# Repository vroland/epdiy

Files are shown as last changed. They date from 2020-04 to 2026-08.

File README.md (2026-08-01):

  

EPDiy E-Paper Driver
=======================================

EPDiy is a driver board which talks to affordable E-Paper (or E-Ink) screens, which are usually sold as replacement screens for E-Book readers. Why are they interesting?

* Easy on the eyes and paper-like aesthetics
* No power consumption when not updating
* Sunlight-readable

Ready-made DIY modules for this size and with 4bpp (16 Grayscale) color support are currently quite expensive and / or slow.
The EPDiy controller can drive the bare display modules, e.g. from old e-Readers, which are available for 20$ (small) / 30$ (large) on ebay!
Additionally, since it is based on the ESP32S3 (V7) / ESP32 (V2-V6) microcontroller, it features WiFi and Bluetooth connectivity.

The EPDiy driver board targets a range of E-Paper displays, as shown in the table below.
As the driving method for all matrix-based E-ink displays is more or less the same, only the right connector and timings are needed.
The current V7 board has three different display connectors, other display will require an adapter board.

The controller is optimized for the use with LiPo batteries, featuring a LiPo charger and ultra-low deep sleep current.

This project supports a driver for the ESP-IDF and Arduino. For installation instructions, please refer to the [documentation](https://epdiy.readthedocs.io/en/latest/getting_started.html#getting-your-board).
Note that for epdiy V7, update speeds are significantly lower when using the Arduino IDE, because it does not allow to change
the sub-optimal cache configuration.

Get Inspired
------------

The `examples` directory contains some example applications like a weather station or a screen diagnostic test. 
If you want to build something more useful though, how about:

- A serial terminal for connecting to a raspberry pi: [video](https://cdn.hackaday.io/files/1681937195969312/terminal_demo.mp4) [repository](https://github.com/vroland/epdiy-terminal)]
- A Music Player Daemon (MPD) dashboard: [repository](https://github.com/vroland/epdiy-mpd)]
- Firmware for displaying images directly from Immich (Self-Hosted Photo Management) [epdiy-immich](https://github.com/vroland/epdiy-immich)
- An e-Paper picture frame: [video](https://www.youtube.com/watch?v=r7AcNQsSZUw)
- And more to come!

Building It
-----------

On the [EPDiy Hardware Page](https://vroland.github.io/epdiy-hardware/), you'll find a list of all boards and variants, adapters, and helpers.
Next to each board, there are manufacturing files (gerbers), Bill of Materials (BoM), part placement files,
and 3D models ready to use!

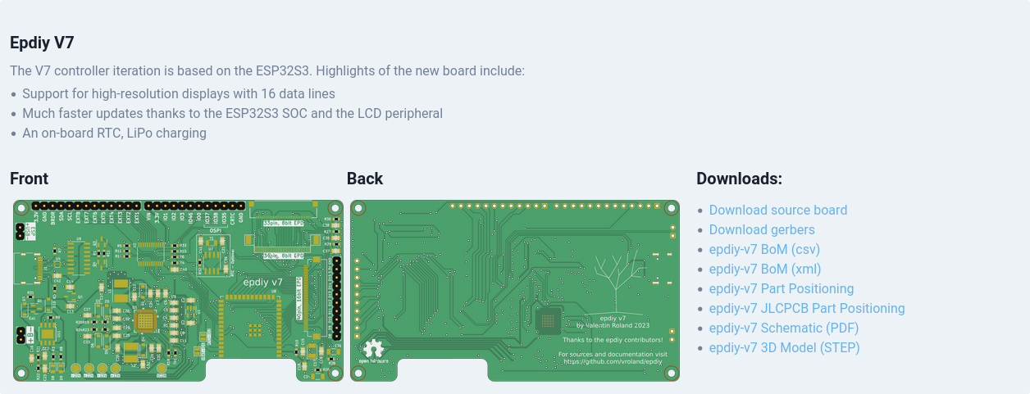
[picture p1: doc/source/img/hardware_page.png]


For ordering from JLCPCB for example, ordering is as easy as downloading the zipped gerbers, BoM, and placement file
and uploading them. The process is very similar for other manufacturers, check your vendor's documentation for details.
Don't forget to oder adapters if the board doesn't have connectors for your specific display.

The current latest version is epdiy V7, beased on the ESP32S3. 
Older versions are also available on the hardware page.

#### Contributing Hardware

Want to contribute your own board variant or adapter? 
Check out the [epdiy-hardware repository](https://github.com/vroland/epdiy-hardware) for instructions.

Gettings Started
----------------

For instructions and more information visit the [documentation](https://epdiy.readthedocs.io/en/latest/getting_started.html)!

Join the Discussion
----------------

 -  Matrix Community: +epdiy:matrix.vroland.de
 - Slack: See badge

Displays
--------

|Name |Size |Resolution|Compatible|Connector|Pin count|Compatible since pcb version|Notes
| --: | --: | --: | --: | --: | --: | --: | --: |
| ED060SC4 | 6"  | 800 x 600<br>167 PPI | yes, tested | FH26W-39S-0.3SHW(60) | 39  | v2  | |
|ED097OC4|9.7"|1200 x 825<br>150 PPI|yes, tested|XF2M-3315-1A|33|v2|Cheap, inferior contrast
|ED097TC2|9.7"|1200 x 825<br>150 PPI|yes, tested|XF2M-3315-1A|33|v2|Slightly higher price, better contrast
|ED097OC1|9.7"|1200 x 825<br>150 PPI|yes (should work)|XF2M-3315-1A|33|v2|Cheap, inferior performance
|ED047TC1|4.7"|960 x 540<br>234 PPI|yes, tested|40-pin|40|LILYGO 4.7" EPD|Supported only by 4.7" e-paper board by LILYGO
| ED050SC5 | 5" | 600 x 800<br>200 PPI | yes, tested | THD0510-33CL-GF | 33 | v5 |
| ED050SC3 | 5" | 600 x 800<br>200 PPI | yes (should work) | THD0510-33CL-GF | 33 | v5 |
| ED052TC4 | 5.2" | 1280 x 720<br>284 PPI | yes (should work) | WP27D-P050VA3 | 50 | v5 |
| ED133UT2 | 13.3" | 1600 x 1200<br>150 PPI | yes, tested | adapter board | 39 | v2 | Adapter Board required, also PENG133D
| ED060XC3 | 6" | 758 x 1024<br>212 PPI | yes, tested | THD0515-34CL-SN | 34 | v5 | Cheapest, good contrast and resolution
| ED060XD4 | 6"  | 758 x 1024<br>212 PPI | yes, tested | THD0515-34CL-SN | 34 | v5 |
| ED060XC5 | 6"  | 758 x 1024<br>212 PPI | yes (should work as ED060XC3) | THD0515-34CL-SN | 34 | v5 |
| ED060XD6 | 6"  | 758 x 1024<br>212 PPI | yes (should work as ED060XC3) | THD0515-34CL-SN | 34 | v5 |
| ED060XH2 | 6"  | 758 x 1024<br>212 PPI | yes (should work as ED060XC3) | THD0515-34CL-SN | 34 | v5 |
| ED060XC9 | 6"  | 758 x 1024<br>212 PPI | yes (should work as ED060XC3) | THD0515-34CL-SN | 34 | v5 |
| ED060KD1 | 6"  | 1072 x 1448<br>300 PPI | yes (should work as ED060XC3) | THD0515-34CL-SN | 34 | v5 |
| ED060KC1 | 6"  | 1072 x 1448<br>300 PPI | yes (should work as ED060XC3) | THD0515-34CL-SN | 34 | v5 |
| ED060SCF | 6" | 600 x 800<br>167 PPI | yes, tested | THD0515-34CL-SN | 34 | v5 | Different flex cable shape
| ED060SCN | 6" | 600 x 800<br>167 PPI | yes (should work as ED060XC3) | THD0515-34CL-SN | 34 | v5 | Different flex cable shape
| ED060SCP | 6" | 600 x 800<br>167 PPI | yes (should work as ED060XC3) | THD0515-34CL-SN | 34 | v5 | Different flex cable shape
| ED060SC7 | 6" | 600 x 800<br>167 PPI | yes (should work) | AXT334124 | 34 | v5 | connector dropped in v6
| ED060SCG | 6"  | 600 x 800<br>167 PPI | yes (should work) | AXT334124 | 34 | v5 | connector dropped in v6
| ED060SCE | 6"  | 600 x 800<br>167 PPI | yes (should work) | AXT334124 | 34 | v5 | connector dropped in v6
| ED060SCM | 6"  | 600 x 800<br>167 PPI | yes (should work) | AXT334124 | 34 | v5 | connector dropped in v6
| ED060SCT | 6"  | 600 x 800<br>167 PPI | yes, tested | AXT334124 | 34 | v5 | connector dropped in v6
| ED078KC1 | 7.8"  | 1872 x 1404<br>300 PPI | yes, tested | FH12-40S-0.5SH | 40 | v7 | 16 data lines

Troubleshooting
---------------

The following list is compiled from past experiences and GitHub issues:
 * **The displayed image displays only part of the image.** Make sure to select the correct display type as described [here](https://epdiy.readthedocs.io/en/latest/getting_started.html#selecting-a-display-type).
 * **The existing image fades / darkens when updating a partial screen region.** Make sure the VCOM voltage is [calibrated](https://epdiy.readthedocs.io/en/latest/getting_started.html#calibrate-vcom) for your specific display.
 * **The second third of the image is replaced with the last third.** This seems to be a timing issue we could not yet quite figure out the reason for. For a workarround or suggestions please [join the discussion](https://github.com/vroland/epdiy/issues/15).
 * **The ESP does not boot correctly when external periperals are connected.** Make sure not to pull GPIO12 high during boot, as it is a strapping pin internal voltage selection (https://github.com/vroland/epdiy/issues/17).
 * **The ESP power consumption in deep sleep is too high.** Add `rtc_gpio_isolate(GPIO_NUM_12);` to your solution. See also [Configuring IOs (Deep-sleep Only)](https://docs.espressif.com/projects/esp-idf/en/latest/esp32/api-reference/system/sleep_modes.html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).

LilyGo Boards
---------------

### Supported LilyGo Boards

| Board | Display | Board Definition | Notes |
| --: | --: | --: | --: |
| LilyGo T5 4.7" | ED047TC1 | `epd_board_lilygo_t5_47` | Original T5 4.7" |
| LilyGo T5 S3 E-Paper Pro | ED047TC1 | `epd_board_v7` | ESP32-S3 based, includes GT911 touch, PCF8563 RTC, BQ25896/BQ27220 battery management |

### Power Management

There are several differences with these boards.
One particular one is the way the LilyGo handles power to the display the official lilygo code has two states.
This is now handled in epdiy in a different way to the lilygo code.
**epd_poweroff()** completely turns the power off to the display and the other peripherals of the lilygo.
The new function **epd_powerdown()** keeps the peripherals on (this allows the touch functions to continue to work).
**epd_poweroff() should always be called before sleeping the system**
You can still use touch to wake the screen with the following.
In Arduino it works like this.
`epd_poweroff();`

 `epd_deinit();`

 `esp_sleep_enable_ext1_wakeup(GPIO_SEL_13, ESP_EXT1_WAKEUP_ANY_HIGH);`

 `esp_deep_sleep_start();`

### I2C Bus Sharing

EPDIY now uses the ESP-IDF master bus/device I2C driver on IDF 5.x and newer.

Existing programs can keep calling `epd_init(...)` and EPDIY will create and own the board's default I2C bus.

If your application already owns an ESP-IDF I2C master bus, pass it in during initialization:

```c
i2c_master_bus_handle_t bus = ...;
EpdI2cConfig i2c_config = {
    .bus_handle = bus,
};
EpdInitConfig init_config = {
    .i2c = &i2c_config,
};

epd_init_with_config(&epd_board_v7, &ED047TC1, EPD_LUT_64K, &init_config);
```

When a bus handle is provided, EPDIY will attach its TPS65185/PCA9555 devices to that bus and leave bus ownership to the caller.

More on E-Paper Displays
------------------------

 * List of E-Paper devices and their screens: https://e-ink-reader.ru/chg_dsp_en.php (thanks, @mcer12)
 * Reverse engineering of display pins, possible starting point for alternative drivers: https://linux-sunxi.org/PocketBook_Touch_Lux_3 (thanks, @mcer12)
 * Reverse engineering and explanation on driving EPDs: http://essentialscrap.com/eink/index.html
 * Earlier take on driving 6" EPDs with an ESP32, basis of original power circuit: http://spritesmods.com/?art=einkdisplay&page=1
 * Related Hackaday projects: https://hackaday.io/project/21607 https://hackaday.io/project/11537

If you know any other useful resources or have suggestions, please comment on #31!

Hackaday Project
----------------

For more details, see the project page on Hackaday: https://hackaday.io/project/168193-epdiy-976-e-paper-controller

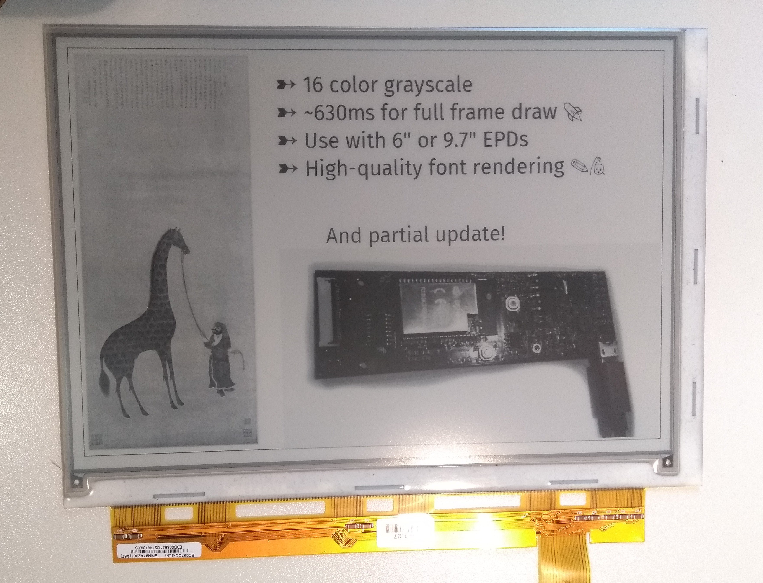
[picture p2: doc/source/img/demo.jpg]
demo image

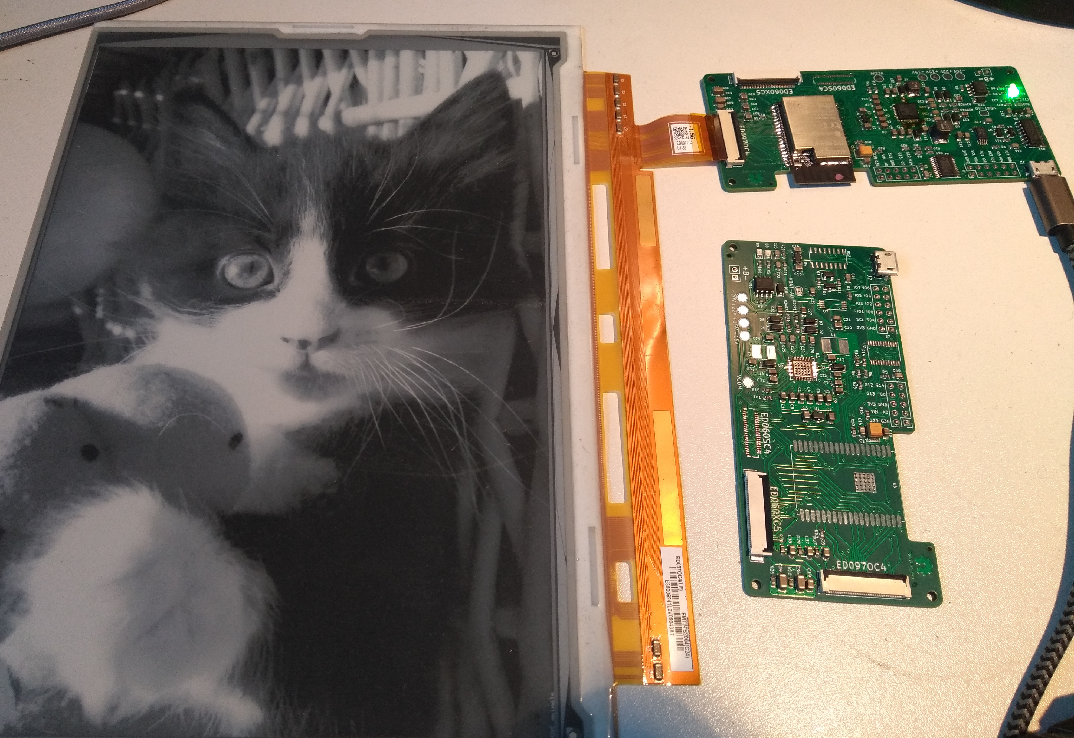
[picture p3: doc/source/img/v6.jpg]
board front


Licenses
--------

The weather example is Copyright (c) David Bird 2018 (except for minor modifications). Please refer to `examples/weather/README.md` for details.

The board and schematic are licensed under a  <a rel="license" href="https://creativecommons.org/licenses/by-sa/4.0/">Creative Commons Attribution-ShareAlike 4.0 International License</a>.

Firmware and remaining examples are licensed under the terms of the GNU Lesser GPL version 3.
Utilities are licensed under the terms of the MIT license.

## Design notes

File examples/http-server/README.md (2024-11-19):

# HTTP server

Runs an HTTP server that will draw images on the screen.  
Useful for setting up a small digital frame that can be remotely controlled.  

## Config
1. In `main/server.h`, edit `WIFI_SSID` and `WIFI_PASSWORD` to match your wifi config
2. In `main/main.c`, edit `n_epd_setup` to refer to the right EPD screen

## Running
flash (`idf.py flash`), then connect the EPDiy to a power source (computer is fine).  
The endpoints are:
1. `GET /`, prints the screen temp / height / width as headers
2. `POST /clear`, clears the screen
3. `POST /draw`, expects:
   1. a body that is a binary stream already encoded to EPDiy's standards (like the one in `dragon.h`).
   2. Headers `width`, `height`
   3. Optional headers `x`,`y` (default to 0)
   4. Optional header `clear`, if set to nonzero integer will force-clear the screen before drawing

## Helper script
`send_image.py` is a friendlier client.
```bash
$ ./send_image.py ESP_IP info
EpdInfo(width=1024, height=768, temperature=20)

$ ./send_image.py ESP_IP clear
# Clears the screen

$ ./send_image.y ESP_IP draw /tmp/spooder-man.png
# Draws on screen
```
Thanks to argparse, all arguments are visible with `--help`.  
Requires `requests` and `PIL` (or Pillow)

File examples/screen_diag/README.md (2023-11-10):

# Screen Diagnostics
This example app implements a simple shell to allow you to tinker with the display. You have access to all drawing functions from the _epd driver_, as well as system information, etc.

There are also pre-programmed algorithms (e.g. `render_stairs`, `render_grid`) which can be used to find pixel errors or display incompatibilities.

The `screen_diag` examples requires ESP-IDF v5.x or newer.

## Setup
Don't forget to set your display type in `epd_init` in `epd.c`!

First you need to flash the firmware:
```sh
idf.py flash
```

After that, you can enter the shell environment with:
```sh
idf.py monitor
```

Please note the [known issues](https://docs.espressif.com/projects/esp-idf/en/stable/esp32/api-guides/tools/idf-monitor.html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) of the IDF Monitor for limitations.

## Usage
You can get a full list (see below) of all available commands with: `help`.

```
system_restart
  Restarts the system.

free_heap_size
  Returns the free heap size.

dump_heaps_info  [<caps>]
  Dumps heap information of all heaps matching the capability.
        <caps>  Heap caps to print. Default: MALLOC_CAP_DEFAULT

dump_tasks
  Dumps all tasks with their names, current state and stack usage.

chip_info
  Dumps chip information.

firmware_info
  Dumps information about the ESP-IDF and the firmware.

get_time
  Returns the time in microseconds since boot.

get_mac  [<interface>]
  Returns the MAC address for the given interface or the pre-programmed base
  address.
   <interface>  Either "wifi_station", "wifi_ap", "bluetooth" or "ethernet"

get_rotation
  Get current screen rotation.

set_rotation  <rotation> [--inverted]
  Changes screen rotation.
    <rotation>  screen rotation: "horizontal" or "portrait"
    --inverted

get_width
  Print screen width.

get_height
  Print screen height.

get_pixel  <posx> <posy>
  Get pixel color in front buffer.
        <posx>  x position
        <posy>  y position

set_pixel  <posx> <posy> [<color>]
  Set pixel color in front buffer.
        <posx>  x position
        <posy>  y position
       <color>  color. default value: 0 (0x00)

clear_screen
  Clear the entire screen and reset the front buffer to white.

full_clear_screen
  Same as clear_screen, but also tries to get rid of any artifacts by cycling
  through colors on the screen.

get_temp
  Returns the ambient temperature.

power_on
  Turns on the power of the display.

power_off
  Turns off the power of the display.

draw_hline  <x> <y> <len> [<color>]
  Draw horizontal line.
           <x>  start x position
           <y>  start y position
         <len>  length of the line
       <color>  default value: 0x00

draw_vline  <x> <y> <len> [<color>]
  Draw vertical line.
           <x>  start x position
           <y>  start y position
         <len>  length of the line
       <color>  default value: 0x00

draw_line  <start_x> <start_y> <end_x> <end_y> [<color>]
  Draw line between two points.
     <start_x>  start x position
     <start_y>  start y position
       <end_x>  end x position
       <end_y>  end y position
       <color>  default value: 0x00

draw_rect  <x> <y> <width> <height> [<color>]
  Draw a rectangle.
           <x>  top left x position
           <y>  top left y position
       <width>  square width
      <height>  square height
       <color>  default value: 0x00

fill_rect  <x> <y> <width> <height> [<color>]
  Draw a filled rectangle.
           <x>  top left x position
           <y>  top left y position
       <width>  square width
      <height>  square height
       <color>  default value: 0x00

draw_circle  <center_x> <center_y> <radius> [<color>]
  Draw a circle.
    <center_x>  center x position
    <center_y>  center y position
      <radius>  circle radius
       <color>  default value: 0x00

fill_circle  <center_x> <center_y> <radius> [<color>]
  Draw a filled circle.
    <center_x>  center x position
    <center_y>  center y position
      <radius>  circle radius
       <color>  default value: 0x00

draw_triangle  <x0> <y0> <x1> <y1> <x0> <y0> [<color>]
  Draw a triangle from three different points.
          <x0>  first edge x position
          <y0>  first edge y position
          <x1>  second edge x position
          <y1>  second edge y position
          <x0>  third edge x position
          <y0>  third edge y position
       <color>  default value: 0x00

fill_triangle  <x0> <y0> <x1> <y1> <x0> <y0> [<color>]
  Draw a filled triangle from three different points.
          <x0>  first edge x position
          <y0>  first edge y position
          <x1>  second edge x position
          <y1>  second edge y position
          <x0>  third edge x position
          <y0>  third edge y position
       <color>  default value: 0x00

write_text  [-s] <x> <y> [<color>] <msg>
  Write text message to the screen using the sans-serif font by default.
           <x>  x position
           <y>  y position
       <color>  default value: 0x00
   -s, --serif  Use serif font rather than sans-serif.
         <msg>  Text to be printed.

render_stairs  [<slope>] [<width>] [<color>]
  Render multiple diagonal lines across the screen.
       <slope>  angle by which each diagonal line is drawn. default value: 3
       <width>  thickness of each diagonal line. default value: 100
       <color>  default value: 0x00

render_grid  [<gutter>] [<color>]
  Renders a grid across the whole screen. At a certain gutter size, cell info
  will be printed as well.
      <gutter>  default value: 75
       <color>  default value: 0x00

help
  Print the list of registered commands
```

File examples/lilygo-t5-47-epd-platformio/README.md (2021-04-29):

# LilyGo T5 4.7 Inch Example

This is an example project to kick-start you using the LilyGo T5 4.7 inch EPaper display.

It also incorporates a few deepsleep methods to show how to use deepsleep to effectively save battery.
Additionally, it inherits and modifies the battery calculation code provided in examples by the manufacturer.

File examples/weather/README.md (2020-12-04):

Weather display example
=======================================

This is **port of project https://github.com/G6EJD/ESP32-e-Paper-Weather-Display by David Bird 2018** to work with ED097OC4 Kindle display and this driver.
**Please note that David Bird (https://github.com/G6EJD) owns the copyright to this software!** Only minor modifications where made for it to run with the epdiy driver.
THe  license details are outlined in **License.txt**.

Building It
-----------

 - Girst you need to install Arduino esp-idf as a component https://github.com/espressif/arduino-esp32/blob/master/docs/esp-idf_component.md (the easiest way is to put it into components folder of ESP-IDF)
 - Put Arduino JSON https://github.com/bblanchon/ArduinoJson into components/arduino/
 - Dont forget to insert your Wi-Fi settings and openweathermap API key into owm_credentials.h
 - If you want to add more fonts, firmware may not fit into 1M and easiest way to fix it is to edit components/partition_table/partitions_singleapp.csv and change 1M to 2M

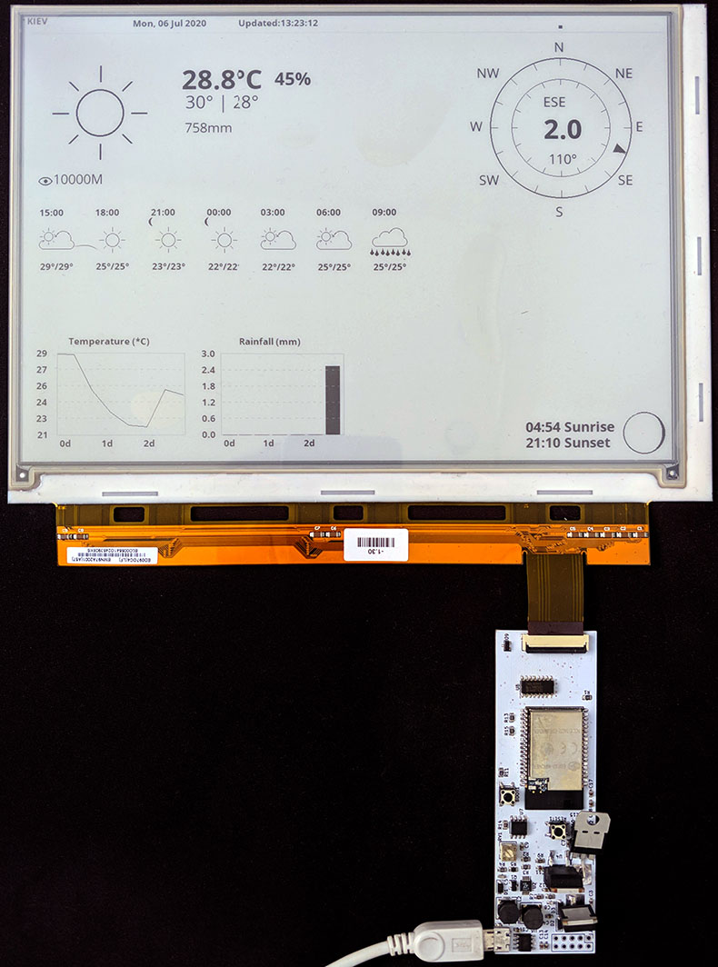
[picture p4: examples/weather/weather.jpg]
weather image


License
-------

This software, the ideas and concepts is Copyright (c) David Bird 2014 and beyond.

All rights to this software are reserved.
 
It is prohibited to redistribute or reproduce of any part or all of the software contents in any form other than the following:

 1. You may print or download to a local hard disk extracts for your personal and non-commercial use only.

 2. You may copy the content to individual third parties for their personal use, but only if you acknowledge the author David Bird as the source of the material.

 3. You may not, except with my express written permission, distribute or commercially exploit the content.

 4. You may not transmit it or store it in any other website or other form of electronic retrieval system for commercial purposes.

 5. You MUST include all of this copyright and permission notice ('as annotated') and this shall be included in all copies or substantial portions of the software and where the software use is visible to an end-user.
 
THE SOFTWARE IS PROVIDED "AS IS" FOR PRIVATE USE ONLY, IT IS NOT FOR COMMERCIAL USE IN WHOLE OR PART OR CONCEPT.

FOR PERSONAL USE IT IS SUPPLIED WITHOUT WARRANTY OF ANY KIND, EXPRESS OR IMPLIED, INCLUDING BUT NOT LIMITED TO THE WARRANTIES OF MERCHANTABILITY, FITNESS FOR A PARTICULAR PURPOSE AND NONINFRINGEMENT.

IN NO EVENT SHALL THE AUTHOR OR COPYRIGHT HOLDER BE LIABLE FOR ANY CLAIM, DAMAGES OR OTHER LIABILITY, WHETHER IN AN ACTION OF CONTRACT, TORT OR OTHERWISE, ARISING FROM, OUT OF OR IN CONNECTION WITH THE SOFTWARE OR THE USE OR OTHER DEALINGS IN THE SOFTWARE.

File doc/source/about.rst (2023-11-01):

About
=====

EPDiy is a driver board for e-Paper (or E-ink) displays.

.. _display_types:

Display Types
-------------

The EPDiy driver board targets multiple E-Paper displays.
As the driving method for all matrix-based E-ink displays seems to be more or less the same, only the right connector and timings are needed.
A table of supported displays is mainained in the :code:`README.md` file.

Some of the supported displays are showcased below.

ED097OC4
~~~~~~~~

The ED097OC4 was the original target of this project. It is an 9.7 inch screen, with a resolution of 1200 * 825 pixels (150dpi).
It is fairly available on Ebay and AliExpress, for around 30$ to 35$. 
There is also a lower contrast version (ED097OC1) which also works. 

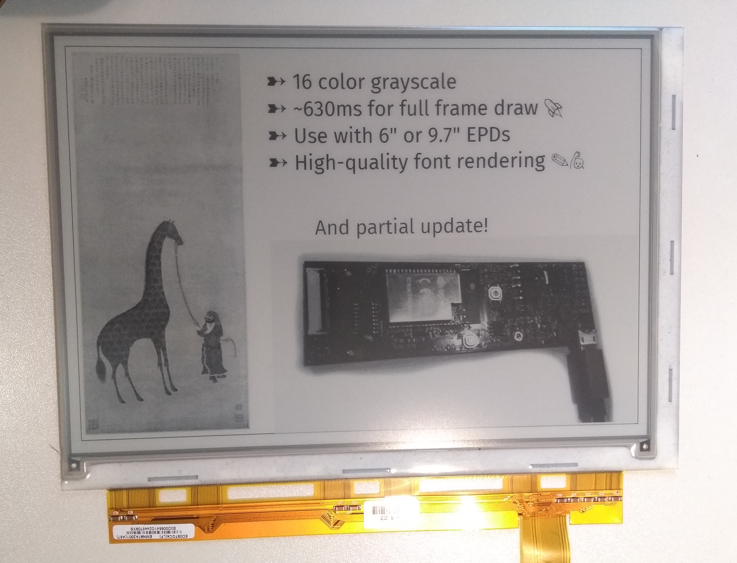
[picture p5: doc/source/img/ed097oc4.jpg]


ED060SC4
~~~~~~~~

This is a 6 inch display, with a 800 * 600 resolution. With 150dpi as well, it has about half the total display area of the ED097OC4.
To connect this display, the 39-pin connector on the back has to be populated.
It is also the display a lot of experimentation was done with (see Thanks To), so there are alternative controllers available.
Besides the obvious difference in size, this display is cheaper (~20$) and also refreshes slightly faster than the ED097OC4.

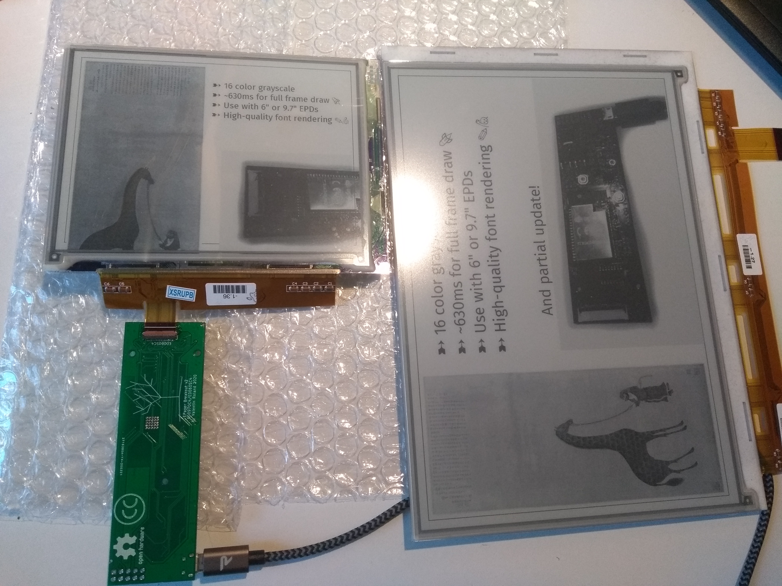
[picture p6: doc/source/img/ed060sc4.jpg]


ED097TC2
~~~~~~~~

Information on this display should be taken with a grain of salt. One of the displays I ordered as ED097OC4 came as ED097TC2,
and upon testing it also exhibited noticably better contrast and a more responsive electro-phoretic medium. 
The ribbon connector looked like a ED097TC2 as well, or like the `9.7 inch screens offered by Waveshare <https://www.waveshare.com/9.7inch-e-Paper.htm>` (which is sold for a lot more).
If you are on the lookout for such a display keep in mind the authenticity of my sample is disputable and resolution and connector type should be double-checked.

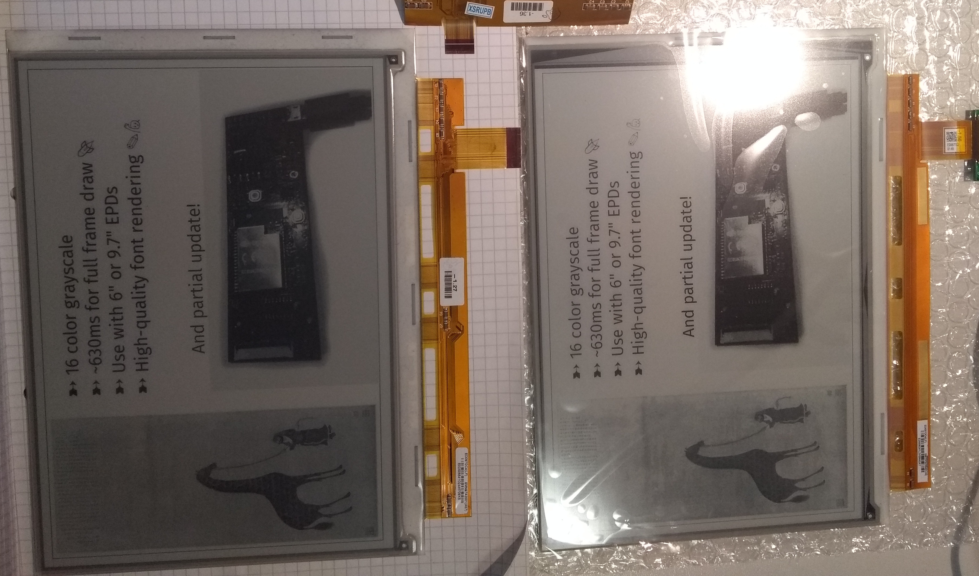
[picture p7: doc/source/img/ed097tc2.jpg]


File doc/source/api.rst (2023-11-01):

.. _pub_api:

Library API
===========

Highlevel API
-------------
.. doxygenfile:: epd_highlevel.h

Complete API
------------
.. doxygenfile:: epdiy.h

Internals
----------
.. doxygenfile:: epd_internals.h

Board-Specific Extensions
-------------------------
.. doxygenfile:: epd_board_specific.h

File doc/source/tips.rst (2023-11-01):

Tips & Tricks
=============

Temperature Dependence
----------------------

The display refresh speed depends on the environmental temperature.
Thus, if your room temperature is significantly different from ~22°C, grayscale
accuracy might be affected when using the builtin waveform.
This can be mitigated by using a different timing curve, but this would require calibrating the display timings at that temperature.
If you did this for some temperature other than room temperature, please submit a pull request!

Deep Sleep Current
------------------

Board Revision V5 is optimized for running from a battery thanks to its low deep sleep current consumption. 
In order to achieve the lowest possible deep sleep current, call
::

    epd_deinit()

before going to deep sleep. This will de-initialize the I2S peripheral used to drive the diplay and bring the pins used by epdiy to a low-power state.
You should be able to achieve a deep-sleep current of less than 13µA.
If your deep-sleep current is much higher, please check your attached peripherals.
With some modules, you have to isolate GPIO 12 before going to deep sleep:
::

    rtc_gpio_isolate(GPIO_NUM_12)

Adding a New Display
--------------------

This section is work-in-progress.

- Add display definitions in :code:`displays.c` and :code:`epd_display.h`.
- Include waveform in :code:`bulitin_waveforms.c`
- Calibrate timing curve in :code:`scripts/generate_epdiy_waveforms.py`.
- Add to the list of displays to build waveforms for in :code:`Makefile`
- Document

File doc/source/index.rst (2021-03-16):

.. EPDiy documentation master file, created by
   sphinx-quickstart on Sat Apr 18 23:41:08 2020.
   You can adapt this file completely to your liking, but it should at least
   contain the root `toctree` directive.

The EPDiy Driver Board
======================

.. toctree::
   :maxdepth: 2
   :caption: Quickstart:

   about.rst
   getting_started.rst
   filegen.rst
   tips.rst
   api.rst

EPDiy is a driver board which talks to affordable E-Paper (or E-Ink) screens, which are usually sold as replacement screens for E-Book readers. Why are they interesting?

* Easy on the eyes and paper-like aesthetics
* No power consumption when not updating
* Sunlight-readable

Ready-made DIY modules for this size and with 4bpp (16 Grayscale) color support are currently quite expensive. This project uses Kindle replacement screens, which are available for 20$ (small) / 30$ (large) on ebay!

The EPDiy driver board targets multiple E-Paper displays. As the driving method for all matrix-based E-ink displays seems to be more or less the same, only the right connector and timings are needed. The EPDiy PCB features a 33pin and a 39pin connector, which allow to drive the following display types: ED097OC4, ED060SC4, ED097TC2

:ref:`getting_started`



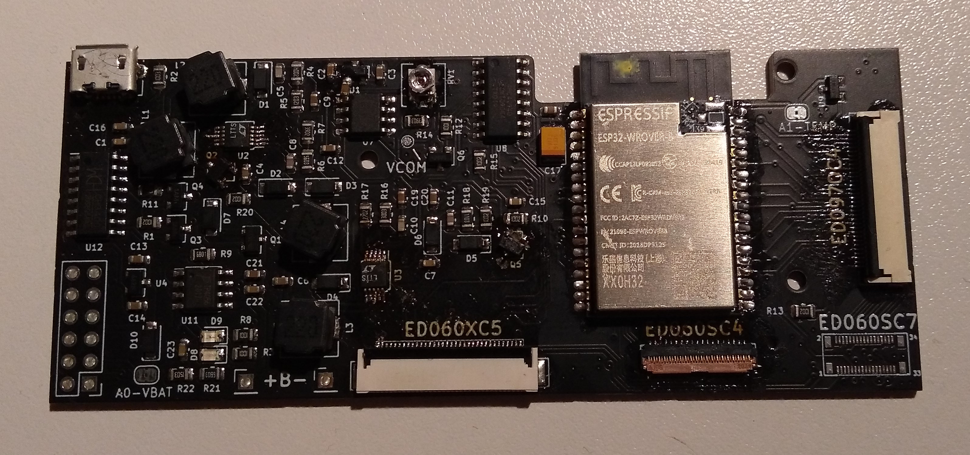
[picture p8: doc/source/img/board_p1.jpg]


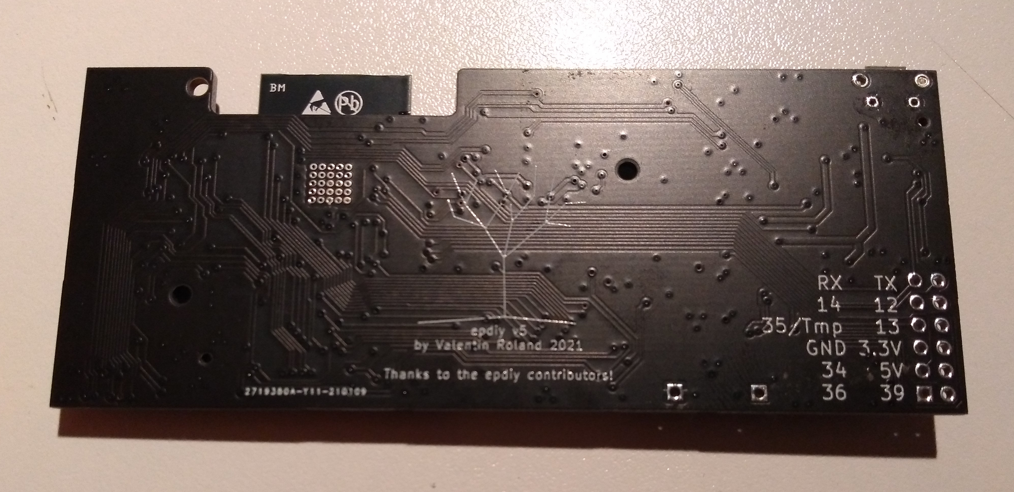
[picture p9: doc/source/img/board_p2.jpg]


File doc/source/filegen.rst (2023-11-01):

Fonts, Images, Waveforms
========================

The ESP32 is, although fairly capable, still a microcontroller.
Thus, with memory and computational resources limited, it is useful to do as much of the processing
for displaying fonts and images on a computer.

Epdiy comes with scripts that convert fonts, images and waveforms to C headers,
that you can then simply `#include` in your project.

Generating Font Files
---------------------

Fonts can only be used by the driver in  a special header format 
(inspired by the Adafruit GFX library), which need to be generated from TTF fonts.
For this purpose, the :code:`scripts/fontconvert.py` utility is provided.
.. code-block::

    fontconvert.py [-h] [--compress] [--additional-intervals ADDITIONAL_INTERVALS] name size fontstack [fontstack ...]

The following example generates a header file for Fira Code at size 10, where glyphs that are not found in Fira Code will be taken from Symbola:
.. code-block::

    ./fontconvert.py FiraCode 10 /usr/share/fonts/TTF/FiraCode-Regular.ttf /usr/share/fonts/TTF/Symbola.ttf > ../examples/terminal/main/firacode.h

You can change which unicode character codes are to be exported by specifying additional
ranges of unicode code points with :code:`--additional-intervals`.
Intervals are written as :code:`min,max`. 
To add multiple intervals, you can specify the :code:`--additional-intervals` option multiple times.
.. code-block::

    ./fontconvert.py ... --additional-intervals 0xE0A0,0xE0A2 --additional-intervals 0xE0B0,0xE0B3 ...

The above command would add two addtitional ranges.

You can enable compression with :code:`--compress`, which reduces the size of the generated font but comes at a performance cost.

If the generated font files with the default characters are too large for your application,
you can modify :code:`intervals` in :code:`fontconvert.py`.

Generating Images
-----------------

The process for converting images is very similar to converting fonts.
Run the :code:`scripts/imgconvert.py` script with an input image, an image name and an output image.
.. code-block::

    imgconvert.py [-h] -i INPUTFILE -n NAME -o OUTPUTFILE [-maxw MAX_WIDTH] [-maxh MAX_HEIGHT]

The image is converted to grayscale scaled down to match fit into :code:`MAX_WIDTH` and :code:`MAX_HEIGHT` (1200x825 by default). 
For accurate grayscale it is advisable to color-grade and scale the image with a dedicated tool before converting it.

:code:`OUTPUTFILE` will be a C header with the following constants defined: 

- :code:`{NAME}_width` is the width of the image
- :code:`{NAME}_height` is the height of the image
- :code:`{NAME}_data` is the image data in 4 bit-per-pixel grayscale format.

Converting Waveforms
--------------------

.. note:: Waveform Timings and V7

    Epdiy builtin waveforms currently use variable frame timings to reduce the number
    of update cycles required. This is currently not implemented in V7. Hence, for best results it is recommended to use Vendor waveforms where available, which use constant frame timings.

In comercial applications, displays are driven with information in so-called `Waveform Files`.
These specify how which pulses to apply to the pixel to transition from one gray tone to another.
Unfortunately, they are display-specific and proprietary.
However, while they are not freely available, they can be obtained through a number of ways:

- Being a large customer of E-Ink. Unfortunately not doable for mere mortals.
- Finding them scattered around the internet. Examples include the `MobileRead forums <https://www.mobileread.com/>`_ or the `NXP Support forum <https://community.nxp.com/t5/i-MX-Processors/How-to-convert-wbf-waveform-file-to-wf-file/m-p/467926/highlight/true>`_.
- Extracting from e-Reader firmware.
- Extracting from a flash chip that comes with some displays. More on this can be found `here <https://hackaday.io/project/21168-fpga-eink-controller/log/57822-waveforms-binary-extract>`_.

Waveforms usually come with a :code:`*.wbf` file extension.

If you have a matching waveform file for your display, it can be converted to a waveform header that's usable by epdiy.
The advantage of using vendor waveforms include the availability of all implemented modes in the waveform file, support of a wide range of temperatures and more accurate grayscale-to-grayscale transitions.

As a first step, the waveform data is extracted from the original waveform file and stored in JSON format.
This can be done using a `modified version <https://github.com/vroland/inkwave>`_ of `inkwave <https://github.com/fread-ink/inkwave>`_ by Marc Juul.

Once a matching JSON file is obtained, the :code:`scripts/waveform_hdrgen.py` utility can be used to generate a waveform header, which can be included in your project.
::

    waveform_hdrgen.py [-h] [--list-modes] [--temperature-range TEMPERATURE_RANGE] [--export-modes EXPORT_MODES] name

With the :code:`--list-modes` option, a list of all included modes is printed.
:code:`name` specifies a name for the generated :code:`EpdWaveform` object.
Additionally, the temperature range and modes to export can be limited in order to reduce file size.
An example for the usage of this script can be found in the top-level :code:`Makefile` of the epdiy repository.

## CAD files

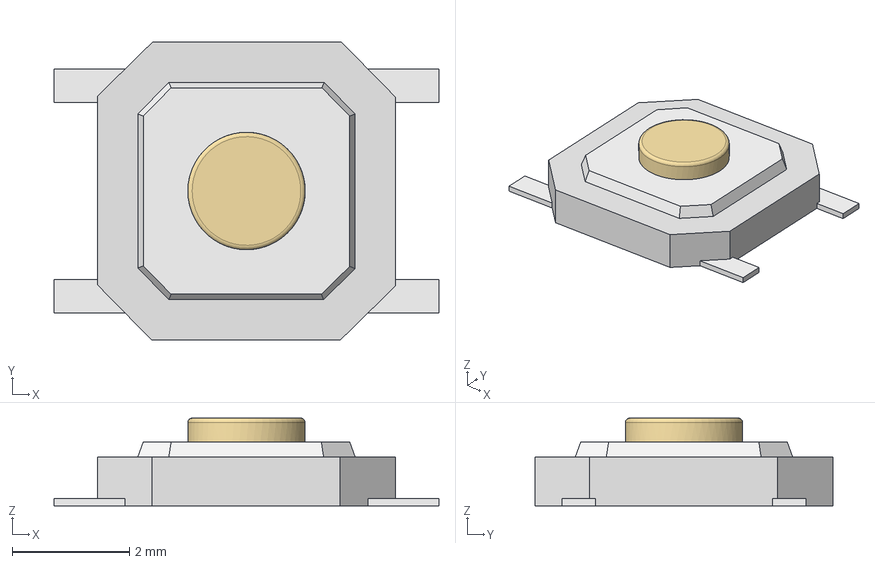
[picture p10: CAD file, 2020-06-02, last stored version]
hardware/epdiy-v7/3dmodels/Tactal Switch - SMD (5mmx 5mmx1.5mm).stp
6.58 x 5.10 x 1.50 mm

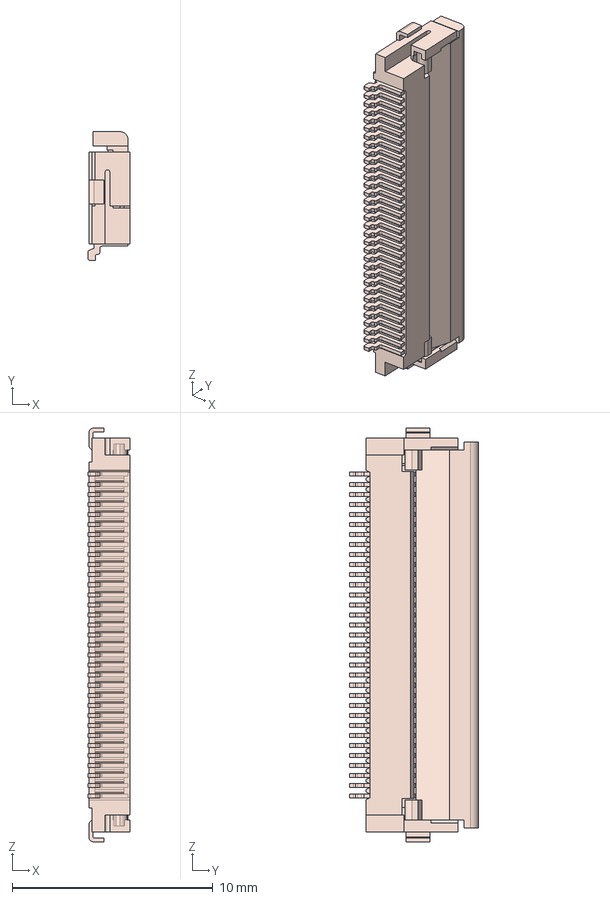
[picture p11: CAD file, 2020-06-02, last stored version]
hardware/epdiy-v7/3dmodels/FH12-33S-0.5SH.stp
2.10 x 6.40 x 20.6 mm

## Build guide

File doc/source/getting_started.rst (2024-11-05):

.. _getting_started:

Getting Started
===============

Getting your Board
------------------

At the current point in time, there is no official way to buy an epdiy board.
Fortunately, it is quite easy to order your own. There are many PCB prototype services
that will manufacture boards for a low price.

To use one of those services, upload the "Gerber files", usually provided as a zip file,
to the service.
You can find all the available hardware listed on the `Hardware Page <https://vroland.github.io/epdiy-hardware/>`_.

Choosing and Finding Parts
~~~~~~~~~~~~~~~~~~~~~~~~~~

The parts needed to assemble the epdiy board are listed in the `BOM.csv` file.
Commodity parts like resistors, capacitors, coils and diodes are interchangable, as long as they
fit the footprint. 
When in doubt, use the parts listed in the BOM file.

However, some parts are not as common, especially the connectors. 
Most of them can be found on sites like eBay or AliExpress. 

Tips:
    - Use the WROVER-B module instead of other WROVER variants.
      This module exhibits a low deep sleep current and is proven to work.
    - The LT1945 voltage booster seems to be out of stock with some distributors,
      but they are available cheaply from AliExpress.

Calibrate VCOM
--------------

.. note:: Only for old boards

   This is only needed with boards prior to revision 6.
   From revision 6 onwards, VCOM can be set in software via :code:`epd_set_vcom(..)`.

EPaper displays use electrical fields to drive colored particles.
One of the required voltages, VCOM (Common Voltage) is display-dependent
and must be calibrated for each display individually.

Fortunately, the VCOM voltage is usually printed on the display, similar to this:

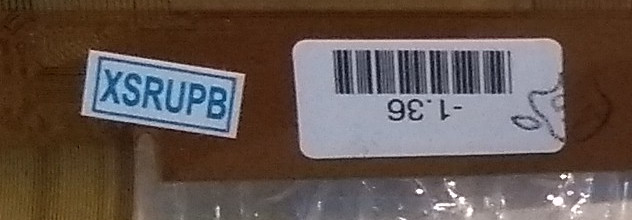
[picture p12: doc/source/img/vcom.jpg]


The VCOM value is usually between -1V and -3V. 

For the v6 board, you can enter the desired VCOM value in :code:`make menuconfig`.
No interaction is required.

For the older models, use the trimmer marked :code:`RV1`.
You can measure the VCOM on the VCOM test pad (if your board has one) or directly
at the amplifier:

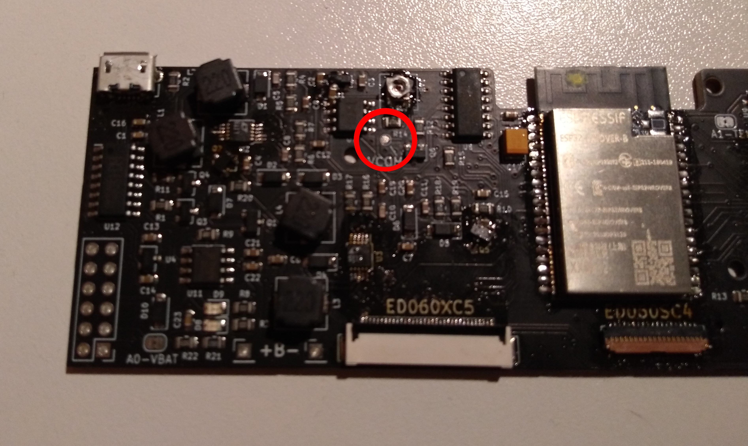
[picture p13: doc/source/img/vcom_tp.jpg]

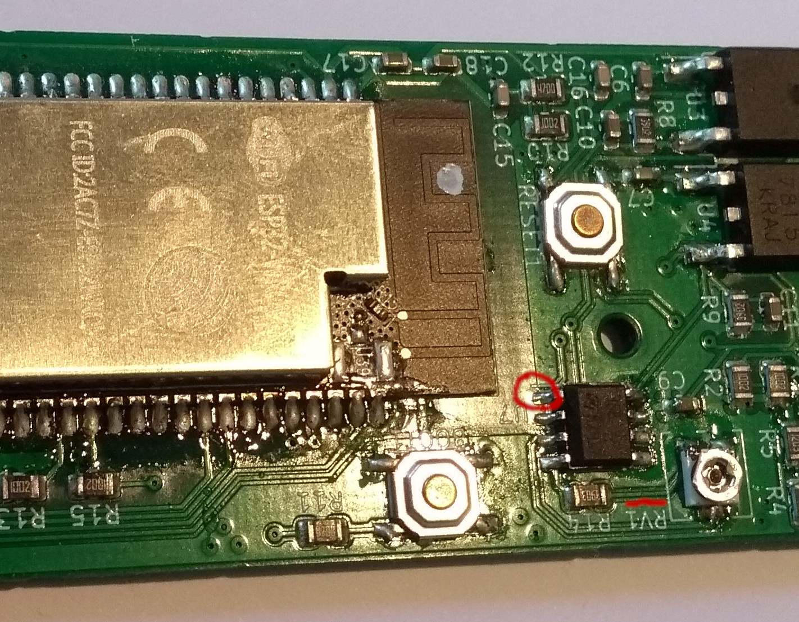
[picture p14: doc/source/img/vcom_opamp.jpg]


.. note::
    
    Although most boards do not have it yet, image quality for partial updates can be improved by adding a (at least) 4.7uF capacitor between VCOM and GND. 
    When adding this capacitor, take care with the polarity as VCOM is negative!

Flashing the demo
-----------------

First, connect you board with the computer. In the output of :code:`lsusb` you should find something like:
::

    Bus 001 Device 048: ID 1a86:7523 QinHeng Electronics HL-340 USB-Serial adapter

This means the serial adapter is working and there a serial like :code:`/dev/ttyUSB0` should appear.

Next, make sure you have the `Espressif IoT Development Framework <https://github.com/espressif/esp-idf>`_ installed. 
The current stable (and tested) version is 5.3.
For instructions on how to get started with the IDF, please refer to their `documentation <https://docs.espressif.com/projects/esp-idf/en/stable/get-started/>`_.

Then, clone the :code:`epdiy` git repository (and its submodules):
::

    git clone --recursive https://github.com/vroland/epdiy

Now, (after activating the IDF environment) you should be able to build the demo:
::

    cd examples/demo/
    idf.py build

Hold down the :code:`BOOT` button on your board, while quickly pressing the :code:`RESET` button. 
The ESP module is now in boot mode. 
Upload the demo program to the board with
::

    idf.py flash -b 921600 && idf.py monitor

Pressing :code:`RESET` a second time should start the demo program, which will
output some information on the serial monitor.

With the **board power turned off**, connect your display. 
Power on the board.
You should now see the demo output on your display.

Use with esp-idf
----------------

The neccessary functionality for driving an EPD display is encapsulated in the :code:`components/epdiy` IDF component.
To use it in you own project, simply copy the :code:`epdiy` folder to your project-local :code:`components` directory.
The component sould be automatically detected by the framework, you can now use
::

    #include "epdiy.h"

to use the EPD driver's :ref:`pub_api`.

Selecting a Board and Display Type
~~~~~~~~~~~~~~~~~~~~~~~~~~~~~~~~~~

With epdiy 2.0.0, the display type and board are set via :code:`epd_init()`.

Enable SPI RAM
~~~~~~~~~~~~~~~~~~~~~~~~
The ESP32-WROVER-B comes with an additional 8MB external PSRAM, where the :code:`epdiy` is going to store ~2MB for its internal frame buffers. 
Since it is dynamically allocated from the heap, and the built-in SRAM of ~160KB is insufficient, we need to enable external SPI RAM first.

Open the :code:`menuconfig` again (see above) and navigate to :code:`Component config -> ESP32-Specific -> Support for external, SPI-connected RAM` and enable it.

Use with Arduino
----------------

Epdiy can be used as an Arduino library. Additionally, epdiy comes with board definitions for its supported boards, which must be installed separately. 
To install epdiy to work with the Arduino IDE (>= 1.8), place the downloaded repository into your Arduino libraries folder.

Alternatively, it is possible to use the `Arduino APIs as an IDF component <https://github.com/espressif/arduino-esp32/blob/master/docs/esp-idf_component.md>`_,
which allows you to use the Arduino ecosystem (Except for a different build process).
This gives you full access to ESP-IDF options.

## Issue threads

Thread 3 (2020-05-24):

Terminal example 'crashes' USB Serial chip

sebastius, 2020-05-24:
Somehow the terminal example annoys the USB Serial chip so much it causes to re-enumerate on the USB bus :sunglasses:

Tried it with the Arduino IDE serial terminal, screen and IDF monitor. All three are gloriously killed :+1:

Could be a shitty driver on my Linux Mint, could be a bad chip. Haven't seen this behaviour before in other USB serial chips, this is my first board with the CH330.

sgeisler, 2020-05-24:
Interesting, when does that happen? I haven't actively experienced that so far, but maybe I just didn't notice? But my setup is a bit hacky too: let IDF monitor configure the serial port and then pipe the output of `script` to it to mirror a local shell for testing.

sebastius, 2020-05-24:
Oh it might be power related, it hangs my entire hub.

vroland, 2020-05-25:
Ha, that's interesting. So far I have not been able to reproduce it with neither of my machines...
Which kernel version are you using? And it does not happen with the other examples?

sebastius, 2020-05-25:
It seems to be a problem when i'm doing both serial AND updating the eink. Maybe i ordered the wrong parts and have an overcurrent problem. Or a lack of capacitors on the main 5v and 3.3v rails. No clue yet.

It also breaks the USB connection in Windows. Its probably hardware :)

vroland, 2020-05-25:
Hm, jup, seems to be hardware. When I've got the time I can test it on a Raspberry Pi, which is not known for its particularly stable usb power, so I might be able to reproduce it there.

vroland, 2020-05-26:
Hm, I've tried it with my raspberry pi, still no unexpected behaviour :/

sebastius, 2020-05-27:
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

My problem is definetly in the capacitor area (this is the 3.3v rail at the CH330N chip) . Will debug further!

sebastius, 2020-05-27:
More digging: this also happens on the 5v rail. Added a 10nF cap to the CH330N, no effect.

sebastius, 2020-05-28:
Quick question: the LT1945 seems to be powered of the 3.3v rail instead of the 5v rail. Why is that?

sebastius, 2020-05-28:
I fixed it. So what i did was cut the trace supplying the P-fet with 3.3v and hooked it up to the 5v rail. Apparantly the LT1945 and subsequent stuff draw too much power and they destroy the 3.3v rail. I noticed in the PDF that an older version had it hooked up to 5v, so i took a chance.

vroland, 2020-05-28:
Thanks a lot, @sebastius! And yes, as you mentioned in https://github.com/vroland/epdiy/issues/4, I should really update some artifacts.
The LT1945 was hooked up to the 3.3v rail to be able to power the board via 3.3v only (without USB), as this was in-spec according to the data sheet.
Have you tried adding a larger cap on the 3.3V rail? I'm just curious if there is an easy way to fix that, which does not drop support for 3.3V operation... Due to the Covid-19 Situation I do not have access to an ocscilloscope, buf it looks loke it could definitely be useful to have a look at such things.

sebastius, 2020-05-28:
i've doubled the 3.3v and 5v caps (both now 2x 10uF) but to no avail.

I recommend reverting to the 5v supply on that signal but allow people to use a range of voltages there. Anything above 3.3v and below 12v will probably work (depending on the mosfet, if the CH330n isn't present and the caps are capable of that voltage.

I've left the pullup R1 on the 3.3v rail by the way.

vroland, 2020-05-28:
Hey, that sounds reasonable. I'm just learning by doing here myself, since my background is more in software than in hardware ;)
Btw, could you me which exact regulators you used? Just to compare the model with mine.

sebastius, 2020-05-28:
Solved with the 5v patch and is fixed in #6.

I've used the C125862, UZ1086L-33-TN3-R which has nearly the same specs but apparantly not good enough :)

vroland, 2020-05-28:
I was using the AMS1086CD-3.3, but aside from a slightly lower dropout voltage they seem pretty similar...

Closed 2020-05-28.

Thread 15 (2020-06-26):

Image is corrupted in demo

mmib, 2020-06-26:
Hi and thanks for good project, got the following issue:

Midle 1/3 part of screen is filled using last 1/3 part of image: https://photos.app.goo.gl/NrU67cK5Pw3RJGog6
build board using gerber files from June 04 2020

If change
dev->fifo_conf.tx_fifo_mod = 1;
to
dev->fifo_conf.tx_fifo_mod = 0;
or play with clock dividers i managed to get 2 dragons. But can't get correct image

https://photos.app.goo.gl/JamvfDV5eNeDf52q6

vroland, 2020-06-26:
Did you select the correct display type as described in https://epdiy.readthedocs.io/en/latest/getting_started.html#selecting-a-display-type?

mmib, 2020-06-26:
Hi, yes, selected correct display type (tried all 3 types).
ESP-IDF: tried 4.0.1 and last release version from github
Have ESP32-WROVER board  which seems old version and not ESP32-WROVER-B
Cmake is 3.13.0 which comes with ESP-IDF on Windows (also tried 3.18.0)

Always got same results :)

vroland, 2020-06-26:
Could you send me the firmware .elf - file so I can test it with my board? This should tell us wether it is a software or hardware issue.

mmib, 2020-06-26:
sure, here it is https://drive.google.com/file/d/100nq3WojXUwFnXGf2NzVIdWlf5WL_-Bs
(I changed loop to updated screen just once per 600 seconds)

vroland, 2020-06-26:
Hm, your firmware works fine for me. Do you have a list of components you used? What is the revision of your ESP32-WROVER module (should be shown when flashing)?

mmib, 2020-06-26:
Wow, that is bad news for me :)

Chip is ESP32D0WDQ6 (revision 1)
Features: WiFi, BT, Dual Core, 240MHz, VRef calibration in efuse, BLK3 partially reserved, Coding Scheme 3/4

List of components (excluding resistors and capacitors):
https://eu.mouser.com/ProductDetail/356-ESP32-WROVER
https://eu.mouser.com/ProductDetail/863-MC74HC4094ADG
https://eu.mouser.com/ProductDetail/584-LT1945EMS%23PBF
https://eu.mouser.com/ProductDetail/579-MCP9700AT-E-TT
https://eu.mouser.com/ProductDetail/595-LM358BAIDR
https://eu.mouser.com/ProductDetail/653-XF2M-3315-1A
https://eu.mouser.com/ProductDetail/584-LT1086CM-3.3%23PBF
https://eu.mouser.com/ProductDetail/511-L7915ACV
https://eu.mouser.com/ProductDetail/511-L7815CD2T-TR
https://eu.mouser.com/ProductDetail/512-FDN304P

mmib, 2020-06-26:
can it be just wrong gerber files version? - i got it from zip archive in git version from June 04 2020 and it seems it was not tested version

vroland, 2020-06-26:
Hmm, the only thing I see here is that you use a shift register which specifies a lower clock speed, but since that's only used for control signals it should not lead to the image being as it is...
The other demos produce similar results, I assume?

vroland, 2020-06-26:
Yes, those files are untested, but I don't see how any of the changes would produce this error. It seems very regular, like it has something to do with clock speeds. Did you try to reduce the configured APLL frequency directly instead of the clock divider? And turn it down veery low?

mmib, 2020-06-26:
i made 2 boards and got same results. So, it seems it can be issue with gerber files I used. But strange....
Voltages are correct too.
Or maybe It is display issue, but i have 2 displays and same issue on both.

mmib, 2020-06-26:
Yes, tried to play with APLL and got 2 dragons, 4 dragons and very slow but corrupted dragon. Can't manage to get correct dragon

mmib, 2020-06-26:
at least good to know it is something hardware related. Initially i thought some wire could be broken but when managed to get 2 dragons started to play with clock but without any luck.

vroland, 2020-06-26:
The other demos produce similar results?
Hm, I don't quite understand how reducing the frequency would produce 4 dragons, that's strange.
You could try to have a look at the epd_output_row() function in ed097oc4.c, insert some delays and let the display wait until a row is completely written by changing
```
pulse_ckv_ticks(output_time_dus, 50, false);
```
to
```
pulse_ckv_ticks(output_time_dus, 500, true);
```
It's just hard to diagnose anything remotely...

mmib, 2020-06-26:
Yes, i know it is very hard to diagnose it remotely.

Will also get Nexperia 74HC4094, seems avaialble locally. Looks like it is the only part which can make such problems (but still not sure how).

Thank you for help.

vroland, 2020-06-26:
If that's available easily it might be worth a try...

mmib, 2020-06-29:
Hi, so I solder NXP 74HC4094D and got same results :(
Can it be display related? I have ED097OC4(LF) EMN97A2001(A57)
Any ideas what else to try?

Thank you

vroland, 2020-06-30:
Hm, hard to say. Maybe the following things might give us more information:
 * How does the picture look if you choose ED060SC4 as display type?
 * Have you tried cloning the fresh repository and ONLY reducing the i2s APLL frequency?
 * How do partial updates (e.g. in the Demo example) look?

mmib, 2020-06-30:
- ED060SC4: https://photos.app.goo.gl/UEpa2TSdRJ9MYtGv5
- yes, default look is https://photos.app.goo.gl/78jEMeu7YKVroLea7
tried  following frrquincies with same results as above:
```
rtc_clk_apll_enable(1, 0, 0, 2, 3); // 24Mhz
rtc_clk_apll_enable(1, 0, 0, 2, 8); // 12Mhz
rtc_clk_apll_enable(1, 0, 0, 1, 8); // 10Mhz
```
- if rectangle fits into 1/3 of screen then it is ok, if it fits only in 2/3 then not visible, if it contain parts in 3/3 of screen then this part is duplicated in 2/3

mmib, 2020-06-30:
`dev->sample_rate_conf.tx_bck_div_num = 1;`
producing this https://photos.app.goo.gl/xHEsLTFxtePeRDV39 (looks better with old code BLACK_ON_WHITE)

mmib, 2020-06-30:
getting closer...
`rtc_clk_apll_enable(1, 0, 0, 8, 0); //120 Mhz` gives correct image with old code, but then verticals lines start to appear https://photos.app.goo.gl/J6Y6tg7gY1Hk1vGJ7
with new code it looks this way https://photos.app.goo.gl/kgyap7JQGsLfvFoR8
reducing frequency by `rtc_clk_apll_enable(1, 0, 0, 2, 0); // 60 Mhz` makes wrong dragon again

mmib, 2020-06-30:
`rtc_clk_apll_enable(1, 0, 0, 7, 0);` also works, but can't fix bleeding vertical lines

vroland, 2020-06-30:
What? According to the data sheet, the absolute maximum frequency should be 50Mhz... Something is really wrong with the clock here... Can you try to use the bit clock instead of the word clock? for the  CKH signal? (Replace I2S1O_WS_OUT_IDX by I2S1O_BCK_OUT_IDX)

>     * ED060SC4: https://photos.app.goo.gl/UEpa2TSdRJ9MYtGv5
And the normal demo with ED060SC4? Since the dragon demo does not adjust to the smaller width, it will look weird no matter what.

And I should really update the timing table for WHITE_ON_BLACK, since that one is not yet calibrated for the ED097OC4, this is why it looks so white.

mmib, 2020-06-30:
- Demo with ED060SC4 (I2S1O_BCK_OUT_IDX makes no difference both in demo and dragon)  https://photos.app.goo.gl/3UGoe53Tr4iEEk7V6
- Demo with ED060SC4 and `rtc_clk_apll_enable(1, 0, 0, 7, 0);` https://photos.app.goo.gl/tNg8255RBwykgqxA9 (actually same)
- Demo with ED060SC4 and  commented out rtc_clk_apll_enable() (how?)  https://photos.app.goo.gl/mLwcHDkdPzcAXHqR6
- Demo with ED097OC4  and default `rtc_clk_apll_enable(1, 0, 0, 8, 3);`  https://photos.app.goo.gl/LTfb5wi6g7Gm7ihK7`
- Demo with ED097OC4  and `rtc_clk_apll_enable(1, 0, 0, 7, 0);`
- ED097OC4 dragon took 418ms  `rtc_clk_apll_enable(1, 0, 0, 7, 0);` and looks good
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
vroland, 2020-09-13:
@stig3 Good to hear. I think I will just make this frequency setting available as a separate option, independent of the display type. Hope that will cover most variants out there :)

kubasienki, 2020-12-31:
Is this fix included in demo code?

mcer12, 2021-01-05:
@vroland I couldn't resist and bought the cheap $30 ED097OC4 on aliexpress. Only way to have uncorrupted image was to use ED097OC4 LQ profile so thanks for implementing this! It still isn't perfect tho, the display seems very slow comparet to TC1 which is probably a feature but I have an issue where I have to wait (delay) at least 5s in between changes. Without the wait, the display is more and more washed out with each refresh. The darks are washed out around left and top corner a bit, but almost unnoticable when using 10s delay between frames.

mcer12, 2021-01-05:
I should add that VCOM is properly adjusted according to sticker value.

vroland, 2021-01-05:
Hm, since this seems to be a recurring thing this has to be some systematic error. Maybe we're missing something about the timings? Can you take a picture of the display labels to I can compare them with the ones I have?

mcer12, 2021-01-06:
The label says ED097OC4(LF), I will take a photo tomorrow when I have better lighting conditions :)

mcer12, 2021-01-06:
@vroland
https://www.dropbox.com/s/fprhz8l1r6r125v/Photo%2006.01.2021%2010%2011%2006.jpg?dl=0
https://www.dropbox.com/s/8ibcokf2pdaj81q/Photo%2006.01.2021%2010%2011%2038.jpg?dl=0

Seems like the same panel you have so I think yours might be little more forgiving than ours are :) I was experiencing exactly same distortion as on @stig3 's photo. ED097OC4 LQ fixed that but the quality is still not good. You can see on my pictures slightly visible fade on top corner, this is much more visible when I'm not using long delays.

mcer12, 2021-01-06:
Also not sure if it's visible from the picture but it's shifted something like 5 pixels to the right, on the left is 5px white space, on the right is 5px distortion

kubasienki, 2021-01-06:
I can confirm, I've ordered two displays (on separate occasions) from aliexpress and the second shipping only works on low quality profile. But apart from bad contrast it works good.  (Unfortunately first one working on normal profile broke, so I can't compare both labels)

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

mcer12, 2021-01-06:
@kubasienki you don't experience washed out image after several subsequent refreshes? Or faded image on the edge of the display?

vroland, 2021-01-06:
Actually there is a slight difference in the label of mine:
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
Notice how the font in you displays (@mcer12  and @kubasienki )? The "C4" is almost connected while the letters are clearly separated on my display. So your displays are probably at least from the same production run...

vroland, 2021-01-06:
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
Here is a picture of the glass on the back side. Identical with yours`

mcer12, 2021-01-06:
The numbers next to the 9.7" EPD are different, other than that it's identical. It's possible it's some low quality run and that's why it's so cheap (it's the $30 one, free shipping aka the cheapest on ali :) ) If you have any ideas what could cause this, I will try it out. I will have to dig into the library some more when I have time, to try different timings, see how that behaves. But comparing OC4 and TC1 side by side, the TC1 is super fast and crisp, OC4 is visibly slow.

mcer12, 2021-01-06:
The issues with image fading out with subsequent refreshes lead me to think it might be something with voltages. As this issue disappears when I add 10s delay after each refresh. Maybe it's sensitive to disabling / reenabling power (aka display turn off / on) but I tried it without that and it happend as well.

vroland, 2021-01-06:
I'd guess its something about the timings, maybe hold times of some lines. There is also the OE line which is just the source driver enable on the newer displays (e.g. the ED133UT2 or the ED097TC2 have signal diagrams in their datasheet). Maybe the older displays need some driven differently to discharge properly or something?
Problem is, without such a display it is only guesswork for me, but I don't want to spend 30$ on a broken display when I could just get a better one :D

mcer12, 2021-01-06:
@vroland I looked in the datasheets and one significant difference in timing is that clock cycle time is 50ns min. for OC4 and 16.7ns min. for TC1

martinberlin, 2023-07-30:
Can we archive this old nice conversation? Asking to know if that won’t offend any of you ;)

Closed 2023-08-25.

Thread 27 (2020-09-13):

Kindle touch(d01200) screen SPI interface

ashbuilds, 2020-09-13:
Hi :)
Sorry, This is not an issue but just a newbie question.

Really happy to see this repo exist, Thank you for your work. I have an old kindle touch that uses an E-Ink screen `ED060SCG(LF)T1`. I wanted to use this as my DIY project and make use out of it, I'm new to this field so my searches are limited and I'm unable to find a way to connect that screen connector to my Arduino uno. It would be great if you can give me the advice to find a proper SPI interface or display driver for this model. Thank you so much.

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

vroland, 2020-09-13:
Could you post a picture of the actual connector?
With these displays, it is unfortunately not as easy as just plugging it in some adapter. This is because they need some special voltages and have some timing requirements that might are not possible to achieve with an Arduino Uno.
But this is basically why this project exists ;) So if the connector for this display works with this board, you can write firmware for the ESP32 that either drives the display directly or talks to an Arduino over SPI.

ashbuilds, 2020-09-14:
Hi :)
Sounds great. Below are the photos of the connector let me know if not it's clear I'll try to take another. Thanks and have a nice day.
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

vroland, 2020-09-14:
Hmm, I have not yet seen a connector like this on any displays I've tried... So if you could get your hands on a data sheet to find out the pinout and connector type, you could modify the PCB to use this connector :/

ashbuilds, 2020-09-14:
Okay great. I'll do some research and get back to you. Thanks :)

ashbuilds, 2020-09-14:
Hi @vroland :)
After some intense research, I found the connector type and its pinout. Its 34 pin connector and below is the screenshot from the datasheet:
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

Link to datasheet: https://wenku.baidu.com/view/793fba7919e8b8f67d1cb94e.html

Let me know if it's possible to modify the PCB for this connector. Thank you for your help :)

vroland, 2020-09-14:
Hey, nicely done! :) A quick search for the axt434124 looks like it's fairly easy to come by and the pin functions are pretty much the same as for the ED097OC4/TC2. So you should be able to create /find a KiCad part for the connector, wire the pins accordingly and you should be good to go.  Once you have the PCB you might have to experiment a bit with the grayscale timing.
So from what I've seen so far, i am fairly optimistic that this should work :)

mcer12, 2020-09-16:
@ashbuilds @vroland I am more curious about the touch stuff :)

vroland, 2020-09-16:
@mcer12 From what I've seen so far, the touch screen is usually broken out via another connector. Some seem to already have a controller integrated, some have the raw sense lines. So @ashbuilds, is there some other connector as well?

ashbuilds, 2020-09-17:
@mcer12 @vroland Hi :)
In other screens, I saw online they usually do have another connector for touch. I didn't find time to crack open my full kindle but it seems like this screen `ED060SCG` only got one connector as it shows in replacement displays online: http://got.by/21kynj but soon I will do the full teardown of my kindle and keep you updated.

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

mcer12, 2020-09-17:
@ashbuilds  If that's the case then the pinout is incomplete. You will need to give us full datasheet of the display ;)

mcer12, 2020-10-05:
@ashbuilds this should be the same panel, same connector, just differently shaped cable.
https://datasheetspdf.com/pdf/1098542/PrimeView/ED060SCE/1

vroland, 2021-02-28:
The connector is now implemented in V5 and the ED060SCG works.

Closed 2021-02-28.

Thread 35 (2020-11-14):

Beefed up power supply

2dom, 2020-11-14:
Not an issue but a question ... is there a reason why you beefed up the power supply / regulators in the later version of the PCB ?. Cannot believe that the display needs that much power ?

vroland, 2020-11-15:
You mean the double-LT1945 in the latest revision? For most displays, it's about power consumption. Boosting up to 22V, then regulating down wastes energy in battery-powered devices, since the 15V rails actually draw the most current.
Additionally, the displays draw a lot of current during refreshes, at least for a short time. With the 9.7" I haven't noticed any problems with the previous design, but with a 13.3" display I tried the display did not react as fast as it should. With the new revision, this problem went away.

vroland, 2020-11-15:
The reasoning is also that the LT1945 is quite cheap when you source it from AliExpress, but if you don't need the lower sleep current and only use up to 9.7" displays, you will be fine with the previous revision.

2dom, 2020-11-15:
Thanks for the explanation...makes a lot of sense.

Closed 2020-11-16.

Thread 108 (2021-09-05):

In v6 board, U3 U7 fabrication attribute value is "Through hole"

Li-Tianming, 2021-09-05:
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

Is that correct? should it be changed to "surface mount"?

Thanks a lot

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

Li-Tianming, 2021-09-05:
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

Same as U7, so maybe it's a mistake?

vroland, 2021-09-08:
Yes, it should. I'll change it next time I make changes to the PCB :+1:

Closed 2021-11-28.

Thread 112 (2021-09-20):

epd_temperature_init conflicts with LilyGoT54.7 and GPIO_NUM_35

cgreening, 2021-09-20:
I'm using a LilyGoT54.7 board and want to use the buttons - they are connected to `GPIO_NUM_34`, `GPIO_NUM_39` and `GPIO_NUM_35`.

These buttons work fine unless I call `epd_init` after calling that the behaviour becomes quite weird.

`GPIO_NUM_35` is always low when I read from it.

I think this is because the code is trying to use GPIO_NUM_35 to read temperature. Possibly there's a missing preprocessor directive to not do this when either of the these are defined:

```
-DCONFIG_EPD_DISPLAY_TYPE_ED047TC1
-DCONFIG_EPD_BOARD_REVISION_LILYGO_T5_47
```

I'm not sure what should be returned from these functions if there is not temperature sensor and if it will break anything if they are replaced with dummy functions for the LilyGo board.

hpsaturn, 2021-09-25:
Hi, I have maybe a similar situation. With the library from the LilyGo official repository of EPD47 I have right readings of battery level with USB or only with the battery. But with this library, the original library that LilyGO have a fork, I can't read the battery level (ADC) on pin 36 and also pin 35. It only works with USB. Maybe do you know is it a same issue?

cgreening, 2021-09-25:
Make sure you have called both:

```
epd_init(EPD_OPTIONS_DEFAULT);
```

And

```
epd_poweron();
```

It should work if you do both those calls and then try and measure the battery.

hpsaturn, 2021-09-25:
Thanks for your comment. But I already have this flow. I think that it is a different problem, because the official demo fails too like my behavior. The demo only works with USB, with battery not.. I'm going to publish the issue.

cgreening, 2021-09-25:
This seems to work - https://github.com/atomic14/lilygo-epd47-battery

Should probably move off this issue - feel free to open on that repo if it doesn't work.

hpsaturn, 2021-09-25:
It is true, I wrong, because I had a CPU frequency with other value, for this reason in battery mode sometimes the ADC only reached ~2v to 2.9v

Here, in a [Telegram group](https://t.me/esp_es/14163) of ESP32, I showed the last version of my work, works nice!

Thanks!
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

Closed 2021-10-04.

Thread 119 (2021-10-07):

Necessity of PSRAM

dot4qu, 2021-10-07:
I have multiple ESP32 dev boards holding different version of the ESP32-WROOM chip, not the WROVER. This chip doesn't specifically support PSRAM, erroring and rebooting when it's enabled in menuconfig. I've made a separate PCA to serve as a breakout board between the ESP32 and an ED060SC4 that's very similar to the schematic provided in the `hardware/epaper_breakout` directory.

I understand the need for external RAM for larger frame buffers and front/back buffers, but I'm a bit confused on how it's used here. According to comments here https://github.com/vroland/epdiy/issues/21, it's not 100% necessary. Theoretically I should be able to switch all of the `MALLOC_CAP_SPIRAM` to `MALLOC_CAP_8BIT` + comment out the `#ifndef` checking the Kconfig value, and as long as I have enough internal ram I should be okay yeah? (I'd test this but I need to find an 8MB dev board, mine are 4MB)

What's confusing me is that I see a footprint for the bare WROVER chip in the gerber files under `hardware/epaper-breakout` but I can't find any external RAM in the BOM.csv file. What's the point of the preprocessor check for PSRAM being enabled if the board itself doesn't use it? Or is that footprint for some other type of use and those gerbers except an ESP32 dev board w/ external ram connected to the PSRAM pins to be jumped into it?

I feel like I'm missing something really obvious here.

vroland, 2021-10-08:
You are right in that the PSRAM is not 100% necessary, but you can't use the highlevel API and you would need to modify to lower-level API to not use full framebuffers but to calculate the display content on-the-fly. Because this makes things more complex, we require the PSRAM to store full framebuffers.

Regarding WROOM and WROVER: these are both differend *modules* with the ESP32 chip. Under the shielding, there is a PCB with the chip and some auxiliary parts. For the WROVER, these include the PSRAM and flash. That is why there is no RAM chip on the board: The WROVER module already includes it.

dot4qu, 2021-10-08:
Yeah I started in on trying to verify basic drawing without the high level stuff yesterday but I need to do some more bringup testing on my board to make sure all the voltages look good.

Ahh I didn't realize it had on-module ram. I got thrown off by espressif's docs where they recommend two different type of ram to use as PSRAM, hence the assumption it was external to the chip. That makes much more sense. Thanks!

Closed 2021-10-08.

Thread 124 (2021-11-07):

Not correctly incrementing row every draw

dot4qu, 2021-11-07:
I'll preface this with the fact that I'm using my own board that I designed, so I don't expect that much support. I've just gotten to the point where I'm fully stumped on the issue so I figured I'd give you as much info as I have to see if you have any ideas since you've been involved in this much longer than I.

Display is a used Kindle ED060SC4, VCOM is set to same voltage as barcode sticker, -1.3V, using esp-idf with an ESP32-WROVER.

I have 2 issues:
1. The full right side of my display doesn't really work and I can't change it intentionally. This is a non-issue for this post, only mentioning to acknowledge the pics
2. I can correctly address the display to draw along the X axis. However, whatever X coordinate I draw is always copied for the entire vertical column

The more times I draw to an X-coordinate, the darker that vertical line gets. For example:
```
int x_coord = 0;
uint8_t color = 0;     // pretty sure this is black right?
uint8_t line_length = 50;
for (int x = x_coord; x < 300; x += 50) {
    for (int y = 0; y < line_length; i++) {
        epd_draw_pixel(x_coord, y, color, fb);
    }
}
```
I would expect this to result in 6 vertical black lines 50 pixels down from the top. What actually appears is 6 very faint lines from top to bottom of the display. Any line_length below 50 is basically invisible on the display.

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

Instead of drawing 50 pixels, let's bump it to 200
```
...
uint8_t line_length = 200;
... (rest of code identical)
```
This then makes a much darker line instead of the expected 200 pixel tall line.
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

Minimal repro code in this repo: https://github.com/dot4qu/ed060sc4-breakout-driver

My theory is that no matter where on the Y axis the firmware is attempting to draw, it's getting clocked to every single Y coordinate at that X point. Attempting to draw anything horizontal where I keep the X coordinate constant and vary the Y coordinate shows nothing on the display.

I've gone deep into the weeds with a logic analyzer on every control signal comparing to the explanation on [essentialscrap](http://essentialscrap.com/eink/waveforms.html) and everything seems to line up pretty well. There are some weird-ish differences from epdiy (i.e. some wiggling of GMODE before it goes fully high) but the fact that I can correctly clear and draw _kind of_ as expected tells me the overall driving signals are good.

The one part I'm most suspicious of is the logic to latch and advance each row's data, but the LE/OE signals seems to be just fine. The other alternative is that something is weird with the data the ESP is outputting and it's just sending the same values on the DATA lines every row instead of just for the expected row. I captured D0-D7 on my saleae as well but those are weird waveforms and I don't know how to read them.

I've attached the two saleae files if you have the Logic app and wouldn't mind taking a brief look to make sure everything looks okay. It's a free download (~120MB) if you don't but I also totally understand you not wanted to deal with that so I can screenshot different sections/zoom levels if that will help debug.

Appreciate any insight you can give - happy to throw a few bucks your way for your time as well if you have a GitHub sponsor thing or similar.

[epdiy_saleae_captures.zip](https://github.com/vroland/epdiy/files/7492870/epdiy_saleae_captures.zip)

vroland, 2021-11-11:
Hi, looks like a curious issue.
My OS doesn't use AppImages, so a few screenshots would be nice. Maybe the problem is actually something electrical?
For example, maybe something causes the row counter to advance too fast, e.g. through some crosstalk. Then it wraps around or get reset somehow, but that would explain why it draws over the whole height. Fainter / Darker lines could just be an indication of how long / often a line is hit.
Note that the actual latches may have different thresholds on noise than the logic analyzer. So you may not see this crosstalk there. Maybe look again with an oscilloscope?
Having a look at the board layout may also help.

dot4qu, 2021-11-16:
Crosstalk was my biggest fear since my hardware set up is a bit janky. I used the wrong type of shit register in my initial design, and since the correct replacement didn't fit on the SMD footprint I had on the board I had bodge wires soldered from the board pads to a DIP replacement register on a breadboard (you can see it in the photo below).

The good news is that that's not the issue. The very annoying news is that it was literally just a bad screen. I received the second one I ordered from bay, plugged it in, and:

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

So it looks like I'm all set. Thank you for taking the time to try to come up with some possible solutions, I appreciate it!

vroland, 2021-11-17:
Good to hear that it works :) Just having a faulty part is always a very annoying issue :/

Closed 2021-11-16.

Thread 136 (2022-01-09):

Lilygo T5-4.7 - Current leaking to 3v3 rail after epd_poweroff

kaweksl, 2022-01-09:
Hi,

On Lilygo T5-4.7 powered with battery after screen init and epd_poweron() board takes ~115mA@3.6V , and after epd_poweroff() but with ESP32 fully running ( NOT in deep sleep ) power consumption increases to ~235mA .

Looks like some control pins on ESP32 are staying high after epd_poweroff(); and some current passes from esp32 via epd chip clamping diodes to switched off 3v3 rail . This is not happening before epd initialization .

I have noticed after epd_poweroff() esp32 pins IO26 (STH) , IO5(CKH) and IO2(EP_D4) have ~2.2V what may indicate high current draw and drive overload .

Current draw measured with PPK2

EDIT: I need to clarify Lilygo T5-4.7 have rail called VDD3V3 that is powering ESP32 and shift register , it also have 3V3 rail that provide power to epd and LT1945, that rail is controlled by shift register and epd_poweron/poweroff . My theory is that when epd is off, current from esp32 pins go through clamping diodes of epd chip to not powered 3v3 rail and from there wants to power up LT1945 .
This doesn't happen if powered by USB because then EPD and LT1945 is always powered on .

mcer12, 2022-01-19:
First off, this is not the place to debug lilygo board. Even though it's supported by the library, you should open an issue on lilygo page, not here.

It doesn't make any sense for the board to draw double the current when the power to the display is off compared to when display is on. The pins can't even draw such current because to my knowledge ESP pins are limited to around 20mA max. Also, these are signal pins and there's no way the display would draw such excessive current through data lines.

The Lilygo board is not particularly great, it's based off of old outdated epdiy design and it has issues with the display fading out when sleeping.

kaweksl, 2022-01-19:
As far i know ESP32 has Cumulative IO output current  = 1200mA and max ~40mA per IO, that also depends on pin power domain. I have tracked down 3 pins, 3x40mA = 120mA..
What if VDD = 0V, screen (driver IC ) data lines have clamping diodes to VDD (common protection method) , voltage on data lines is higher than on VDD, current is passed trough diode to VDD, something else on VDD is trying to draw that current as not only screen is connected to VDD .

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

I know lilygo is not great design but hardware have been made, software can be changed.

mcer12, 2022-01-20:
The easiest way to test this would be just to pull all the suspected pins low or set them as input after shutting down the display

kaweksl, 2022-01-20:
Here is current draw graph with state annotations
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
From what i observed current draw after poweroff may depend on last "byte" send to screen

kaweksl, 2022-01-20:
I made some changes in display_ops.c

```
static void gpio_setup_out(int gpio, int sig, bool invert) {
  if (gpio == -1)
    return;
  PIN_FUNC_SELECT(GPIO_PIN_MUX_REG[gpio], PIN_FUNC_GPIO);
  gpio_set_direction(gpio, GPIO_MODE_DEF_OUTPUT);
  gpio_matrix_out(gpio, sig, invert, false);
}

void epd_poweron() {
  gpio_num_t I2S_GPIO_BUS[] = {D6, D7, D4, D5, D2, D3, D0, D1};

  gpio_set_direction(STH, GPIO_MODE_OUTPUT);
  gpio_set_level(STH, 1);

  int signal_base = I2S1O_DATA_OUT0_IDX;

  for (int x = 0; x < 8; x++) {
    gpio_setup_out(I2S_GPIO_BUS[x], signal_base + x, false);
  }

  gpio_setup_out(CKH, I2S1O_WS_OUT_IDX, true);

  cfg_poweron(&config_reg);
}

void epd_poweroff() {
  cfg_poweroff(&config_reg);
  gpio_set_direction(D0, GPIO_MODE_INPUT);
  gpio_set_direction(D1, GPIO_MODE_INPUT);
  gpio_set_direction(D2, GPIO_MODE_INPUT);
  gpio_set_direction(D3, GPIO_MODE_INPUT);
  gpio_set_direction(D4, GPIO_MODE_INPUT);
  gpio_set_direction(D5, GPIO_MODE_INPUT);
  gpio_set_direction(D6, GPIO_MODE_INPUT);
  gpio_set_direction(D7, GPIO_MODE_INPUT);
  gpio_set_direction(STH, GPIO_MODE_INPUT);
  gpio_set_direction(CKH, GPIO_MODE_INPUT);
}
```

and now graph looks like that
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

Much better. Offcourse there is better way to implement code above.

ashald, 2022-02-03:
@kaweksl would you submit a pull request?

kaweksl, 2022-02-07:
@ashlad
Code above was just to proof my theory, i don't know if it's proper way to do it or if doesn't create another issues. I don't have enough awareness how epdiy code works and learning make take some time. :P

> P.S.: Without this change I see severe fading if `epd_poweroff()` is called less than a second after `epd_hl_update_screen()` completes, but there is no issue with this change.

Before noticing increased current consumption i was also delaying for ~700ms before poweroff . Good to know that now i can avoid that delay.

ashald, 2022-02-08:
I just received my [PPK2](https://www.nordicsemi.com/Products/Development-hardware/Power-Profiler-Kit-2) and tested whether I can reproduce the above. I can, and the difference is dramatic.

I've got Lilygo T5-4.7 setup to wake up, received data over BLE advertisement, refresh the screen, and go back to deep sleep. I added 3s delay between `epd_pwoeroff()` and `epd_deinit()`, and measure the power consumption with PPK2.

Here is the original profile. Please note gray box in the bottom right corder that sums up the selected area.
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

And here is the same cycle with the above fix.
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

Basically, ~4x difference.

As @kaweksl said above
>  hardware have been made, software can be changed.
I'd love to see this incorporated into the library.

To the best of my understanding, we're sure there is an issue, and we know that it's solvable. Now the question is if the solution is adequate or it may have unwanted side-effects?

@mcer12 what could help us move this forward? Thanks!

mcer12, 2022-02-08:
@ashald modifying the library for broken unofficial hardware isn’t the way. I would merely add a note on wiki about this since it’s such a simple fix. Btw instead of delay, light sleep may be better if you want lowest power consumption possible. Give it a try.

martinberlin, 2022-02-08:
In my opinion if it's just setting the data lines to input in epd_poweroff() it could be done with a precompiler define and a proper for...loop to set the lines only when CONFIG_EPD_BOARD_REVISION_LILYGO_T5_47 is defined.
But I completely agree with @mcer12 on the fact that if a library should be modified for each hardware designs that leak current somewhere, it can be messy and hard to maintain.

errolt, 2022-02-08:
@mcer12 The issue isn't caused by "broken hardware". Phantom powering the display WILL affect all designs. Unless "official hardware" completely disconnects the ESP IO from the display when the display is powered off, and, looking at the schematic, it doesn't disconnect the IO.

IO going to any device that can be powered down should be set low, or set to input, whenever the part they connect to is powered down. ALWAYS.

I have seen this issue in other commercial hardware, where a chip is powered off but the IO going to the chip is allowed to power the chip. In that case sleep power was higher than expected and there was reliability issues.

mcer12, 2022-02-08:
@errolt Except this doesn't happen on official board.

errolt, 2022-02-08:
Maybe the other displays send a "0" as the last byte in all transactions, and the display on the Lilygo doesn't? Dunno. But there isn't significant hardware differences between official and lilygo hardware, not that I can see.

Please don't get me wrong, I'm not arguing.
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
ashald, 2022-02-09:
@kaweksl do you feel like submitting a PR? If no, I can try to do that based on your work.

vroland, 2022-02-09:
I think isolating or setting the outputs to low definitely seems like the correct solution here. Set the pins to output on poweron() and to input on poweroff(). Though I'm not sure if the I2S peripheral stays initialized when changing the pin direction, or if that would require to re-initialize the complete peripheral.

kaweksl, 2022-02-09:
I have tested that and gpio's have to be set back to output with proper matrix setting and i2s don't have to be re-initialized.

I may create some PR but i have to find proper place to put that code.

ashald, 2022-02-09:
@kaweksl don't we want to put it into `display_ops.c` wrapped into `if defined`?
E.g.:
```c
void epd_poweron() {
#if defined(CONFIG_EPD_BOARD_REVISION_LILYGO_T5_47)
  // extra code here
#endif
  cfg_poweron(&config_reg);
}

void epd_poweroff() {
  cfg_poweroff(&config_reg);
#if defined(CONFIG_EPD_BOARD_REVISION_LILYGO_T5_47)
  // extra code here
#endif
}
```
?

martinberlin, 2022-02-09:
Without any desire to criticize just giving my honest opinion @ashald : this looks really ugly. If doing this does not affect any other boards performance it should be done for all, just need to be tested properly when the PR is made.

ashald, 2022-02-09:
Please disregard my above comment. I realized that one can just manipulate pins in their code and then just call original `epd_poweron()` and `epd_poweroff()`. 🤦‍♂️ Given this there's no real need to modify anything in the library.

vroland, 2022-02-10:
From what I gathered, the issue is twofold for the LILYGO board, but still present for the epdiy boards:
For one, there may be current leaking from the control register pins. This is fixed for epdiy boards, but not for the lilygo board.
Secondly, current may leak from the data + clock lines. This is a general issue and could be added to `display_ops.c`, IMO.

martinberlin, 2022-02-10:
Thanks for your followup. Tomorrow I will take some time to measure in my Lilygo board the battery consumption after epd_poweroff() and:

1. Check if setting to low all data pins makes a difference. If it does then this is the easiest way.
2. Or if additionally it's needed to set this to input mode, which is IMHO not the nicest way, since they should be configured again like described above. In that case then this should by done only for LILYGO and if V5 is affected also for this board (Need to check this since I gave mine to my father)

```c
gpio_num_t DATA_BUS[] = {D6, D7, D4, D5, D2, D3, D0, D1, STH, CKH};
for (uint8_t pin = 0; pin < 10; x++) {
   gpio_set_direction(DATA_BUS[pin], GPIO_MODE_INPUT);
   // Or if that keeps consumption up, then direction. But need to configure again in epd_poweron()
   // gpio_set_direction(DATA_BUS[pin], GPIO_MODE_INPUT);
}
```

Will report my findings here after taking the time to put the miliamperimeter in Serie with the battery and see how much it consumes. But I can confirm that in comparison to V6 this board it consumes much more. Lilygo [designs are beautiful](https://twitter.com/martinfasani/status/1491364564017233925) but they never cared much about keeping the lowest possible consumption levels on deepsleep.

ashald, 2022-02-10:
@martinberlin I have PPK2 wired with a JST connector so I can easily check things on my Likygo in terms of power consumption.

If that is helpful, I can quickly run some tests if you'd share exact code you want to try.

martinberlin, 2022-02-10:
As is the code now, after power out in the dragon example, without any deepsleep this is what I see in the testing.

As is without modifying anything:
135 mA
Turning the GPIOs to 0 using gpio_set_level does not change almost anything:
134,6 mA
Turning the GPIOs to input again does consume less:
44,5 mA

Using deepsleep after rendering the dragon
As is without modifying anything:
2.67 mA
Turning the GPIOs to input again does consume less:
2.67 mA

Will leave later a proposed update but it needs to be tested in other boards.

martinberlin, 2022-05-10:
This fix was merged so we can close here

Closed 2022-05-10.

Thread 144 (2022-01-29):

ESP32 S2 board design

mcer12, 2022-01-29:
I am happy to design a board with ESP32-S2 but let's first take our time and discuss this thorroughly. I can't say I understand the low level stuff so it would be best if @vroland and @martinberlin step in and discuss the best pinout for the S2.

What I would like to archieve:
- Get rid of port expander
- Get rid of CH340 and use native USB (native usb could also allow for something like USB display device, maybe)
- Still have some GPIOs left for buttons / inputs

martinberlin, 2022-01-30:
Hi @mcer12
I like the idea a lot. And I will start researching in that direction. In my opinion, if possible, would be great to find a way to supply the required voltages with an existing Board and try to send the data part/ required signals to refresh with an S2 (Would that be possible?)
Because that would be great so we can check if the GPIOs we choose and the I2S DMA transfer works as expected, before investing many hours of design in something that so far no one tested. Also if this design alternative has no PCA9555 then the software has to change.
Maybe it's not a bad idea to make v1 "as is" only without CH340, when my S2-WROVER boards arrive, I will try to flash them without any USB-> Serial, making just a small board with a 5 to 3.3v regulator and see how that goes.
This is a very interesting idea, but it might be not as easy as it seems, also the S2 has GPIOs in the down side so I can imagine the routing of all pins will be more complicated.

mickeprag, 2022-01-30:
After study the datasheet and the source code I find these pins with the following requirements:

Low speed pins (ok to use port expander)
- EP_OE
- EP_MODE
- EP_STV
- SMPS_CTRL
- CTRL+22V
- CTRL-20V
- CTRL+15V
- CTRL-15V

High speed. Used in i2s (for speed?)
- D0..D7
- CKH
- STH

Connected directly to GPIOS in current boards but seems not be time critical?
- CKV
- LE

In total 20 GPIOS needed. All digital and all outputs. 10 of then should preferably be connected to i2s.

martinberlin, 2022-02-05:
Hi @mickeprag ,
I disagree partly with this. CTRL 15 /22 voltages are not pins (at least in V6 boards). If you take the 8 pins that are controlled by IO expander PCA9555 you have this extra pins apart of the 8 data-lines:
TPS_PWR_GOOD (Feedback pin that get's a signal when PWR lines are ready)
TPS_WAKEUP - wakeup signal for TPS651853 Pmic
TPS_VCOM_CTRL - sets the voltage for VCOM
and other 5 that go to the EPD display
EP_CKV
EP_STH
EP_STV
EP_MODE
EP_OE
EP_LE  Latch enable, that I think is the signal that the row is ready to be sent

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

martinberlin, 2022-02-17:
I started with this project, first with a V6 version updating S2 and doing my own board:
https://github.com/martinberlin/H-S2-wrover-dev-board/tree/epd-v1#epdiy-s2-parallel-epaper-controller
First goal for me is to get the voltages and data control lines correctly, so I can work on the software side. I'm afraid my V1 will probably not work, and I have to be wiser next time, making prototypes only with the needed components to try this (And not with USB / battery charge etc)
This can be done in a new version once the whole thing works. But well, you fail, you learn I would say. Will keep you updated once it comes from JLPCB at the end of February and then I manage to solder TPS65185RGZT (a millimeter bigger than the one V6 uses, but limited to 150mA)
And I will buy one Inkster board from @mcer12 as soon as I finish with my move to Barcelona.

mickeprag, 2022-02-17:
Do you know what the issues are with your V1 board?

martinberlin, 2022-02-17:
The issue is just that is the first time I send to fabrication something complex, before I just built small adapters and things alike. So this is my first real PCB design, it's actually a clon of existing V6, but with different design and the changes proposed here (No IO expander, no USB-to-serial chip, and of course S2-Wrover)
The Kicad files are there if you wish to analyze it.

mcer12, 2022-02-23:
One more thing that I just remembered... I use NTC thermistor in my boards instead of temperature sensor. They are super cheap, simple to use an most importantly it's a generic part so it's easily replacable if one vendor stops production. I also hook it up to the EPD power rail so it's only powered when the display is powered.

LCSC part number of the one I use: C95955

martinberlin, 2022-02-24:
Thanks Mcer!
Next week comes my S2 prototype and I could test if the IOs I selected to test the communication to epaper works. If it does, and you want, I can send you a PCB stencil with [TPS65185RGZR](https://www.digikey.de/de/products/detail/texas-instruments/TPS65185RGZR/2674341) soldered. But only if you want to check how it is, otherwise I spare you the distraction ;)

mcer12, 2022-02-24:
What do you mean by PCB stencil with TPS65185RGZR soldered? :)

martinberlin, 2022-02-24:
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 Ordered 5 of this, but only 2 have SMD placing.
For the rest I will solder all by hand, except the TPS65185RGZR, that will solder an expert with right equipment (Already killed a V6 board trying to repair a broken TPS65185). My father that is 65 solders much better than me!

martinberlin, 2022-02-28:
PCBs arrived. After soldiering TPS2113 power mux and getting the expected 3.3v in S2, I proceeded to lash using DFO mode. First of all, this works only after adding an udev rule and your user to the group. Only then dfu-flash detects the device.

```
Determining device status: state = dfuIDLE, status = 0
dfuIDLE, continuing
DFU mode device DFU version 0110
Device returned transfer size 64
Copying data from PC to DFU device
Download[===========] 100%       716800 bytes
```

@mcer the idea is good but I’m afraid is not practical. Because then also to do Serial, you have to enter in dfu mode again (boot pressed + once hit RST) only after that **lsusb** lists an ESP32-S2 device.
And doing monitor I catch the serial at the end, does not trigger a reset, so it’s a bit weird for debugging.
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

mcer12, 2022-02-28:
There must be some automatic process for easy flashing. I need to get my
hands on some S2 dev board to get my hands dirty :D

po 28. 2. 2022 v 21:50 odesílatel Martin ***@***.***> napsal:

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

martinberlin, 2022-03-01:
I think flashing is the least of the problems. The only annoyance is that you need to press BOOT and while is pressed, click on RST so it enters in DFU mode. Usb list devices does not show anything until you do this.
https://docs.espressif.com/projects/esp-idf/en/latest/esp32s2/api-guides/dfu.html

But for me the issue is that if you are developing something, you cannot enter serial mode easily, you need to run [menuconfig like described here](https://blog.espressif.com/dfu-using-the-native-usb-on-esp32-s2-for-flashing-the-firmware-b2c4af3335f1) (Or set some defines if using Platformio) and set the Console channel to CDC mode.
So unless you discover something extra, just taking in account the buttons press, plus the extra dev rule (if on linux) plus the CDC configuration... Well if you use it to flash from time to time, and you design something that really needs to be smaller without space for CH340 then it makes sense. But if not, all this steps to flash the device, and still get uneasy access to serial (DFU mode does NOT send a reset signal like normal monitor mode) then it's a no-go for me.  But you have to really try it for yourself and see if there is any better and faster way to improve what I describe.

martinberlin, 2022-05-14:
Yesterday advanced a bit with my implementation of the S2 board. Now the voltages seem to be stable and if the software side worked in this MCU I think the pixels could be pushed and get a refresh. Still stuck with this:
Thermistor °C: 27
Waiting for PWRGOOD to turn HIGH...
TPS_PWRGOOD ok

```
`Guru` Meditation Error: Core  0 panic'ed (StoreProhibited). Exception was unhandled.

Core  0 register dump:
PC      : 0x4001abc8  PS      : 0x00060030  A0      : 0x8008600e  A1      : 0x3ffc7530
A2      : 0x00000000  A3      : 0x3ffc7540  A4      : 0x00000100  A5      : 0x00000000
A6      : 0x55555555  A7      : 0x55555555  A8      : 0x3ffc7640  A9      : 0x3ffc7500
A10     : 0x00000000  A11     : 0x00001000  A12     : 0x00000001  A13     : 0x000013b7
A14     : 0x00000001  A15     : 0x00000000  SAR     : 0x0000000e  EXCCAUSE: 0x0000001d
EXCVADDR: 0x00000000  LBEG    : 0x00000001  LEND    : 0x000013b7  LCOUNT  : 0x40026895
0x40026895: _xt_user_exc at /home/martin/esp/esp-idf/components/freertos/port/xtensa/xtensa_vectors.S:633

Backtrace:0x4001abc5:0x3ffc75300x4008600b:0x3ffc7540 0x40086093:0x3ffc7680 0x400860da:0x3ffc76b0 0x40085e9e:0x3ffc76e0 0x4008704c:0x3ffc7710 0x40085e2d:0x3ffc7730 0x40085e82:0x3ffc7760 0x4009769e:0x3ffc7780 0x4002db6d:0x3ffc77a0
0x4008600b: epd_push_pixels at /home/martin/esp/projects/epdiy-rotation/src/epd_driver/render.c:67   -->
memcpy(epd_get_current_buffer(), row, EPD_LINE_BYTES);
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
martinberlin, 2022-05-18:
> LoadProhibited, StoreProhibited These CPU exceptions

Fixed this one. I2S instantiation was crap. Now getting the right *pointers (Check last commit)
Very close to getting it to work @mcer12

mcer12, 2022-05-18:
Thats awesome, looking forward to it!

st 18. 5. 2022 v 12:52 odesílatel Martin ***@***.***> napsal:

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

putyn, 2022-08-16:
any update on this topic ? I am too looking to design my own board based on the latest v6 also with some inspiration form @mcer12's design

markbirss, 2022-08-16:
@putyn
I have sent you a Slack invite

martinberlin, 2022-08-16:
> any update on this topic ?

Not yet because I've been busy with client work and my rent is higher in Barcelona so I have less time for fun.
There are some issues with S2, primarily because I've choose wrong PINs, will come back to that later. But also the single I2S that is on board behaves different.
I think the best take would be not to go with S2. Since it's going to be a lot research time to end up with a chip that is anyways NDRD "Not recommended for new designs"
Is a nice exercise but not to make a new PCB. IMHO @mcer12 Let's close this and try to go for a S3 sending the data using the new LCD component just as is done in [Lovyan GFX library](https://github.com/lovyan03/LovyanGFX)

My thinking here after loosing many hours and about 200€ invested in making 2 failed PCBs is to start a completely new design with an ESP32S3 that we can put on top and from that on figure out Routing and correct GPIOS (Don't regret since I learnt a lot for future designs)
Designing kind of Breadboard v1.0 PCB where you can switch pins until you find the right combination. Because it's just false to think you can use any PIN for certain signals, something that costed me a lot of time to learn.

mcer12, 2022-08-16:
@martinberlin agreed!

lanistor, 2022-08-17:
@martinberlin
Agree to use S3.
We tried to retrofit to S2 or S3 some time ago because of insufficient pin count. However, the S2 module issued by Espressif can only support up to 2M of PSRAM, which in many cases cannot meet the memory required for screen rendering, especially if you use a UI library such as lvgl. However, adding PSRAM is not currently in Espressif's plan. If it is developed by ourself, there will be a lot of development and debugging workload.

martinberlin, 2022-08-17:
Thanks for the feedback. Closing here then let's open another S3 issue to plan this when we figure out how to do it.
I suggest making a design where we can just insert an existing Espressif S3 Dev. board so we just need to add the high voltage circuit. No battery charging....Anything except the TPS65185 to generate voltages.
Then we can just play around leaving some handy Jumpers for signals in case we need to route it differently. Otherwise you need to make many versions until you get it working and that is not cheap.

Closed 2022-08-17.

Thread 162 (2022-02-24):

LilyGo turns off touch with poweroff when battery powered.

Yardie-, 2022-02-24:
Hi guys I have been running around in circles thinking my LilyGo was broken
but I found the problem.
the lines in config_reg_vh2.h
```
static void cfg_poweroff(epd_config_register_t *cfg) {
#if defined(CONFIG_EPD_BOARD_REVISION_LILYGO_T5_47)
  // This was re-purposed as power enable.
  cfg->ep_scan_direction = false;
#endif
```
are turning the epd off but also the touch interface when the unit is battery powered.
When this is set to true the touch works fine.

is there a simple way within your framework to change this behavior

the way the lilygo code handles this is to have two functions
epd_poweroff
and epd_poweroff_all
one leaves the value at true the other to false

I can think of several solutions and I can hack out a simple local fix
but it's a simple fix which would probably be best solved by those in the loop of how you want to do this.
Thanks.
Greg

Yardie-, 2022-02-24:
Actually setting the value to true allows the touch to stay active and the blue led goes out when you send the esp into deep sleep but still wakes on touch.
I haven't done a power check but the touch interface is obviously drawing something still being on.

martinberlin, 2022-02-24:
Hi @Yardie-
I will take a look at this. That means that you could theoritically use the Touch INT pin to wake up from deepsleep?

I was trying this but I failed and now I know why. If you cannot make a PR just tell me and I will do it.

@vroland it would be alright to pass a parameter to epd_poweroff + cfg_poweroff for the displays that have touch?
Or you can imagine a better way to do it for Lilygo model?

Yardie-, 2022-02-24:
Thanks @martinberlin
What I thought might be a nice trick is to put two functions inside the define
ie
#if defined(CONFIG_EPD_BOARD_REVISION_LILYGO_T5_47)

continue code with set as true
then end that function then
still within the define
add another function
cfg_poweroff_all ....
and set that  function with the value as false and end the define.
as it does already

then in the caller just add a section

```
#if defined(CONFIG_EPD_BOARD_REVISION_LILYGO_T5_47)

void epd_poweroff_all() {
  cfg_poweroff_all(&config_reg);
  i2s_gpio_detach();
}
#endif

```
with the same in epd_driver.h

then the non lilygo user doesn't even have the function and nothing has changed

I am a little clueless on PRs and GIT
So I would love to handball that to you. :)

Thanks again Martin

BTW
the i2c issue I had was a dodgey RTC.
ESP32's are also quite picky with i2c so the pullups have to be sorted properly.
Anyway that's another story.

Yardie-, 2022-02-24:
Ok I couldn't sleep so I implemented it that way and it seems to work fine.
Now power can be regularly be turned off the epd without affecting the touch then to sleep I did the  following.
The LilyGo will still wake on touch (possibly because of the capacitance change of the touch is picked up by the ESP. But I can't really test that )
```
   esp_sleep_enable_ext1_wakeup(GPIO_SEL_13, ESP_EXT1_WAKEUP_ANY_HIGH);
    epd_poweroff_all();
    epd_deinit();
    esp_deep_sleep_start();
```
Code changes at
https://github.com/Yardie-/epdiy/blob/master/src/epd_driver/config_reg_v2.h
https://github.com/Yardie-/epdiy/blob/master/src/epd_driver/display_ops.c
https://github.com/Yardie-/epdiy/blob/master/src/epd_driver/include/epd_driver.h

I don't know how to do a PR.

Have fun.
Greg

martinberlin, 2022-02-24:
Greg checkout somewhere this:
https://github.com/martinberlin/epdiy-rotation/tree/vroland-master

And try my update. I won't propose any pull request until the maintainer gives his feedback and that can last until beginning of March. Not sure if this is the best way to do it.
I'm not going to duplicate code doing a **cfg_poweroff_all** copy of cfg_poweroff just for the Lilygo exception. I propose to set an additional parameter that can be left empty, or set to true in epd_poweroff()   but leaving it empty will not affect other boards.

Yardie-, 2022-02-24:
@martinberlin Thanks Martin yes the is totally appropriate this was really just a proof of concept thing done at 1 in the morning on a school night. (dad joke)
Which ever way you go guys go I am sure will be the a correct path for the code.

Thanks.
Greg

Yardie-, 2022-02-25:
Sorry @martinberlin Arduino doesn't like having two different definitions.
One in
epd_driver.h as  void epd_poweroff();
and another in
display_ops.h as void epd_poweroff(bool * poweroff_all);

I'll stick with my code for now and at leave it up to you guys to work out.
I know my code ain't pretty but it works ok for now and doesn't change the API

:)
Thanks heaps for your time.

martinberlin, 2022-02-25:
Sorry I could not reproduce it. So I guess my code is also crap ;)
Usually you could have two definitions of the same function that accept different parameters.

Yardie-, 2022-02-25:
@martinberlin :)
AFAIK overriding only works in cpp but in c I didn't think so.
The compiler of Arduino may be playing a little tougher than the ESP compiler.
I think that maybe a combination of both ideas is probably the go.
So only lilygo users have the poweroff_all function and the definition of the
cfg_poweroff(&config_reg);
could be simply wrapped in another define.

It's really just a swing a cat situation.

We have a solution that works.
It just needs to be refined.

Did you try the wake on touch thing.
It surprises me a little if the touch screen is actually turned off that it would send the capacitance down the int wire. But hey I'm not an electrical engineer.
I let way too much smoke out to consider myself  one of those.
:)

vroland, 2022-02-27:
Hm, it's really annoying that they just re-used this pin but well, here we are. Maybe this is something to consider in #160 ?

martinberlin, 2022-02-27:
Exactly. I will add it to my list, thanks @vroland

martinberlin, 2022-06-02:
Reopening this since I rolled back proposed PR from Yardie
This merge in a single commit: fd8a290f68d360c33ba7833487f38566e23e7178
was reversed since it added a function **cfg_powerdown** is a exact copy of existing funcion **cfg_poweroff**

Since after reviewing it, I don't think is a good solution to the problem, and it should be done differently. Ultimately if this is a hardware issue from Lilygo, would be the best to make a different approach on it, after #183 is merged.

Yardie-, 2022-06-03:
Good idea @martinberlin. It will work cleaner and there will be documentation and examples when it does.

martinberlin, 2022-06-04:
Please try this as soon as #185 is resolved.

Yardie-, 2022-07-03:
Sorry @martinberlin  I have not checked this is a while. Basically this is now simply a documentation issue. There is a function that allows touch in the new code. I'll sort that and do a PR

Closed 2022-07-03.

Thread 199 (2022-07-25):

Every X pixels in a row not being drawn to screen

dot4qu, 2022-07-25:
I'm seeing an annoying issue where no matter what I draw to the screen, there are white lines every X column where X is a small, consistent number of pixels. I think a picture will describe what I'm talking about better than words:

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

I'm 99% sure this is **not** an issue with epdiy and is a hardware problem with my board. Most likely a single bad solder joint on the FPC connector or perhaps just enough capacitance on a trace to the display that causes a signal to be a bit late in arriving.

I've seen this behavior with multiple boards I've assembled and different displays. I know they *can* work properly as I've seen totally normal operation too. Interestingly enough, one of my boards worked perfectly fine for the first few days, then devolved into this behavior and hasn't changed since. Which is why I'm very confident it's a HW issue on my end and not the library.

My reason for creating an issue is just to ask what you might think the issue would be. I'm not familiar enough with the protocol for all the different signals that clock in a row of data, write to the display buffer, advance to the next row, etc. Since you're much more familiar with the algorithm involved in writing data, perhaps you know off the top of your head what a likely cause is for this?

It's my understanding that data is written row by row, not column by column. So somehow every X bits written from the frame buffer to the display are getting dropped.

mickeprag, 2022-07-25:
I agree this looks like a hardware issue.

The display is rendered row by row and column by column, just as you say. But each column is 8 pixels and each pixel have its own data signal. So it looks like one or several of the data (d0..d1) signals is broken. Either in the display, cable or board.

dot4qu, 2022-07-25:
ahhh okay that's exactly the info I was looking for, I can throw a scope on d0-d7 to see if any are acting up. Thanks!

dot4qu, 2022-07-25:
Closing this for now and will report back if I find any results for future searches

dot4qu, 2022-07-26:
Sure enough, taking a look at the stretch of castellated edges where my epdiy data pins came out of the esp32, they looked a bit low on solder from reflow. Dumped a bunch in there by hand and voila, no more vertical column artifacts! Extremely happy it was an issue on the esp32 side and not the fine pitch flex connector.

Closed 2022-07-25.

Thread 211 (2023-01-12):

LilyGo T4.7 software port to V5 on Arduino ?

gfaman, 2023-01-12:
Hi,
I modified and added functions on an application with the board and display from LilyGo T4.7 (without touch screen). The original software was the OWM one in the LilyGo and on Arduino.
I'm trying now to port this application to the V5 board, using ED097TC2 display.
I removed the libraries from LilyGo, replace by the epdiy master, add the V5 board in the boards list but now, I'm struggling with many specific functions seems developed by Lilygo.
Anyone tried already successfully to transfer an LilyGo application (with their library) to a V5 board (with epdiymaster library) ?
Thanks,
Laurent

martinberlin, 2023-01-14:
Reopening after discussing this with @gfaman and inviting him to Slack. Please add details of what are the functions that are missing or give errors when you switch to EPDiy.
But in the future please use only EPDiy to start projects and the newest examples from this repository. Starting with Lilygo repository that uses epdiy v.2 is a bad starting step because you will lack the newest updates that are done here.

gfaman, 2023-01-16:
Thanks Martin. Understand the point to start directly with EPDiy. However, I had first the HW of Lilygo and their SW demo was fully compatible with Arduino. That's the original reason.
So far, the transfer from LilyGo to EPDiy is still on going (not yet finished neither working). If someone wants to do it, some points I can highlight:
Add:
#include "epd_highlevel.h"
#define WAVEFORM EPD_BUILTIN_WAVEFORM
EpdFont  currentFont;
EpdFontProperties font_props;
_swap_int function

Replace:
- epd_poweroff_all  by epd_poweroff
- Rect_t by EpdRect
- get_text_bounds by epd_get_text_bounds
- FontProperties by EpdFontProperties
- write_string by epd_write_string  and add a parameter &font_props
- GFXfont  by EpdFont
- in all .h icon file, change some type variables with the epd one
- GFXglyph by EpdGlyph

Missing functions:
- epd_write_line declaration. Moreover, it seems this function has 2 different definitions, one in epd_driver.c and one in font.c

Change:
- drawRect, fillRect (type parameters are differents)

Can compile but not yet link...

Laurent

melmager, 2023-02-04:
just try to compile esphome
since yesterday i got compile error:

Compiling .pioenvs/lilygo/lib56b/epdiy/board_specific.c.o
.piolibdeps/lilygo/epdiy/src/epd_driver/board/epd_board_v6.c: In function 'epd_board_init':
.piolibdeps/lilygo/epdiy/src/epd_driver/board/epd_board_v6.c:102:7: error: 'i2c_config_t {aka struct <anonymous>}' has no member named 'clk_flags'
   conf.clk_flags = I2C_SCLK_SRC_FLAG_FOR_NOMAL;
       ^
.piolibdeps/lilygo/epdiy/src/epd_driver/board/epd_board_v6.c:102:20: error: 'I2C_SCLK_SRC_FLAG_FOR_NOMAL' undeclared (first use in this function)
   conf.clk_flags = I2C_SCLK_SRC_FLAG_FOR_NOMAL;
                    ^
.piolibdeps/lilygo/epdiy/src/epd_driver/board/epd_board_v6.c:102:20: note: each undeclared identifier is reported only once for each function it appears in
*** [.pioenvs/lilygo/lib56b/epdiy/board/epd_board_v6.c.o] Error 1

martinberlin, 2023-02-05:
You can remove that line of clk_flags it should work also without it.
What version of ESP-IDF is using the ESP-Home to compile this? (Or if it's using Arduino ESP32 framework, what version is using)
There can be the solution for this. I'm quite sure this appeared after last ESP-IDF version 5 merge in master #180

martinberlin, 2023-03-03:
Closing this. Unless there is common approval I really would prefer to focus testing and working in the new PCB versions.

@mcer12 & @vroland  IMHO:
Lilygo should maintain and keep updated their own repository based on this one and not the other way around

Closed 2023-03-03.

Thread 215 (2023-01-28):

waveshare 6inch HD e-Paper support

3058132083, 2023-01-28:
https://www.waveshare.net/w/upload/e/e9/6inch_HD_e-Paper_Specification.pdf
There is no mention of the model number in the document, I think it is the same as the ED060KC1

martinberlin, 2023-01-28:
This one should work without any problems. Just get one PCB made or get an Inkster in Tindie and try it out

3058132083, 2023-01-28:
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

The documentation mentions: 25V VGG is required, but in the schematic, it is marked 22V

3058132083, 2023-01-28:
I remade a small size version to use this screen, here is the link, not verified yet
https://oshwhub.com/lxhcat/bing-kou-dian-zi-mo-shui-ping-qu-dong-esp32-xiu-gai-zi-github-kai-yuan-xiang-mu-epdiy
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

martinberlin, 2023-01-28:
Looks nice. But I will try with an existing model that works to make sure it will drive that screen.
I don't think the voltage will be a problem since all this parallel epapers use mostly the same voltages just a different VCOM that usually is printed on an adhesive label on the display.

martinberlin, 2023-06-09:
@3058132083 if you will keep researching on this one then we keep it open.
But if there is no more updates on this till end of June 2023 then this issue will be closed.

markbirss, 2025-04-04:
> https://www.waveshare.net/w/upload/e/e9/6inch_HD_e-Paper_Specification.pdf There is no mention of the model number in the document, I think it is the same as the ED060KC1

I uses this display with a small modification
https://github.com/vroland/epdiy/issues/70#issuecomment-801908988

just tried this again with current tree and v5 board and needed update (idf 5.4)

nano ../../src/displays.c
const EpdDisplay_t ED097TC2 = {
    .width = 1456,
    .height = 1072,
    .bus_width = 8,
    .bus_speed = 22,
    .default_waveform = &epdiy_ED097TC2,
    .display_type = DISPLAY_TYPE_ED097TC2,
};

and for the example you want to compile set #define DEMO_BOARD epd_board_v5 in my case (since im still having v5 board)

nano main/main.c
#ifdef CONFIG_IDF_TARGET_ESP32
#define DEMO_BOARD epd_board_v5

Closed 2023-08-06.

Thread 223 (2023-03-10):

V6 can't work

3058132083, 2023-03-10:
ESP_ERROR_CHECK failed: esp_err_t 0xffffffff (ESP_FAIL) at 0x400deb8c
0x400deb8c: epd_board_poweron at C:/msys64/home/Administrator/epdiy/src/epd_driver/board/epd_board_v6.c:208 (discriminator 1)

file: "C:/msys64/home/Administrator/epdiy/src/epd_driver/board/epd_board_v6.c" line 208
func: epd_board_poweron
expression: tps_write_register(config_reg.port, TPS_REG_ENABLE, 0x3F)

abort() was called at PC 0x4008fdf4 on core 0
0x4008fdf4: _esp_error_check_failed at C:/Espressif/frameworks/esp-idf-v5.0.1/components/esp_system/esp_err.c:47

Backtrace: 0x40082519:0x3ffbad90 0x4008fdfd:0x3ffbadb0 0x400967b5:0x3ffbadd0 0x4008fdf4:0x3ffbae40 0x400deb8c:0x3ffbae70 0x400dd471:0x3ffbaea0 0x400dbf8f:0x3ffbaec0 0x400dc56f:0x3ffbb0c0 0x40163029:0x3ffbb0e0
0x40082519: panic_abort at C:/Espressif/frameworks/esp-idf-v5.0.1/components/esp_system/panic.c:423

0x4008fdfd: esp_system_abort at C:/Espressif/frameworks/esp-idf-v5.0.1/components/esp_system/esp_system.c:153

0x400967b5: abort at C:/Espressif/frameworks/esp-idf-v5.0.1/components/newlib/abort.c:38

0x4008fdf4: _esp_error_check_failed at C:/Espressif/frameworks/esp-idf-v5.0.1/components/esp_system/esp_err.c:47

0x400deb8c: epd_board_poweron at C:/msys64/home/Administrator/epdiy/src/epd_driver/board/epd_board_v6.c:208 (discriminator 1)

0x400dd471: epd_poweron at C:/msys64/home/Administrator/epdiy/src/epd_driver/display_ops.c:40

0x400dbf8f: epd_task at C:/msys64/home/Administrator/epdiy/examples/mpd_status/main/main.c:165

0x400dc56f: app_main at C:/msys64/home/Administrator/epdiy/examples/mpd_status/main/main.c:360

0x40163029: main_task at C:/Espressif/frameworks/esp-idf-v5.0.1/components/freertos/FreeRTOS-Kernel/portable/port_common.c:131 (discriminator 2)

ELF file SHA256: 4b2da0f391ada863

Rebooting...

3058132083, 2023-03-11:
Do you have a discord channel to discuss these issues

vroland, 2023-03-11:
We don't have discord, but there is a slack channel ;)
Apparently the TPS chip does not respond to I2C. Usually this is a soldering issue. Can you double-check the soldering? Also, does the TPS chip show up in an I2C scan?

3058132083, 2023-03-11:
OK,I'll check it.

3058132083, 2023-03-12:
I rewelded, and now there is no error message, but there is still no voltage

martinberlin, 2023-05-05:
> I rewelded, and now there is no error message, but there is still no voltage

Check the return error messages that come from TPS65185 from I2C. If PWR_GOOD signal does not turn HIGH there is some issue with starting the voltage pumps. Check datasheet, I use to have to have some similar issues and I remember it helped to read the values.

https://www.ti.com/product/TPS65185#tech-docs

**Read datasheet with detail:**

- Feature Description (continued)  8.3.8 Fault Handling And Recovery
- Table 8. INT_EN1 Register Field Descriptions
- Table 9. INT_EN2 Register Field Descriptions

Understanding the values of those two registers can be the key to understand what is going on.
Check also that the power to TPS PMIC is stable.

martinberlin, 2023-05-05:
@vroland I think that it will be nice in this topic, for example for the developers starting with V6, to have a Firmware demo that just starts TPS65185 and makes some checks. Also delivers the INT_EN1, INT_EN2 values maybe with some additional info coming from the hardware that we can define. So it's easier to find where the error is.
Because I know how frustrating can be to debug it when you don't get the high voltages running...

mickeprag, 2023-05-05:
This patch at least prints the INT1/2 registers to the log:
https://github.com/vroland/epdiy/pull/248/commits/13fd04ef93b47559c3799bdd5170e538d4fb579b

martinberlin, 2023-06-09:
Thanks Micke,
@3058132083 there is more than 2 months without any feedback from your side. Closing this unless you really want to keep on trying.
Please contact me at the email that you can see in my github profile and I will reopen this then.

Closed 2023-06-09.

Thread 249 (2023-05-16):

new v6 assembled strange display behavior

grelasroberto, 2023-05-16:
Hi, I just assembled a new V6 board with a ESP32 WROVER-B. Tried with ED60SC4(LF) and ED060XC3(LF).  I set up in menuconfig the right dislpay type for both, and the VCOM value for de 60SC4 as the other one does not have any label.  I also enabled the SPI RAM there.

Tried powering from a USB pc port and from several 2A usb supplies, same result.

Checked VCOM at the board and it is ok as well as the -20/22/-15/15 pads.

in the serial console, everything is looking right, no reboots.

I (3724) gpio: GPIO[15]| InputEn: 0| OutputEn: 0| OpenDrain: 0| Pullup: 1| Pulldown: 0| Intr:0
current temperature: 31
I (4617) gpio: GPIO[15]| InputEn: 0| OutputEn: 0| OpenDrain: 0| Pullup: 1| Pulldown: 0| Intr:0
EPD update 682ms. err: 0
I (4773) gpio: GPIO[15]| InputEn: 0| OutputEn: 0| OpenDrain: 0| Pullup: 1| Pulldown: 0| Intr:0
I (4927) gpio: GPIO[15]| InputEn: 0| OutputEn: 0| OpenDrain: 0| Pullup: 1| Pulldown: 0| Intr:0
I (5081) gpio: GPIO[15]| InputEn:

Here is a video of the 60X  running the examples/demo app, looks like there is a kind of progress bar ..

https://youtu.be/KFZbKpk3CzM

The display arrived with a blank screen, after several runs it went gradually turning black, first runs I could barely see some letters displaying.

Does someone got into those similar results?  any clues ?

I can read  -20/22/-15/15 from the pads ONLY when the display is updating, o somehow rendering somthing.  Is this right or they should have constant values?

thank you so much

martinberlin, 2023-05-16:
Hi Roberto,

> can read -20/22/-15/15 from the pads ONLY when the display is updating

yes that’s the way it should be. Most examples do a epd_poweroff and turn the voltages down to save power after updating the display.
Voltages seem all the way correct I wonder if there is some power issue but if TPS power good pin is high should not be.
Please update the video privacy settings since only you can see the YouTube link at the moment.

grelasroberto, 2023-05-16:
Oh sorry, I did update the privacy on the video, thank you for your reply!

grelasroberto, 2023-05-18:
I solved!.. TPS power good was high so started digging each ESP32 pin.  Turns out that due to a falied soldering (residual paste)  EP_D0 and EP_CKV were shorted.

got it working now.

thank you so much!

martinberlin, 2023-05-19:
Great that it worked out!

Closed 2023-05-19.

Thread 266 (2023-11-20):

EC060KH1 aka. SA1452-FOA - 6" Kaleido color panel support

vanarebane, 2023-11-20:
Hi

Can anyone add support for this [color display](https://www.panelook.com/SA1452-FOA_E%20Ink_6.0_EPD_overview_49310.html)?

The datasheet for it is [here](https://1drv.ms/b/s!ApRLRqw9Uoyuvpo5pdrEOj-P9l8xAQ?e=9OrQ1s)

martinberlin, 2023-11-20:
Hello @vanarebane ,
And welcome to epdiy. Please notice that there was an existing issue about this display #88 (Reopened it since I think might be a duplicate of this one since is the same display)
There the author mentions:

> Do you think there is a way to use this board for a 6 inch CFA (Color Filter Array) panel?  The controller timing is the same as ED060SC4, however it seems need another lookup table to show colors.

Did you research how this displays work? Please check my color issue.

> Can anyone add support for this [color display](https://www.panelook.com/SA1452-FOA_E%20Ink_6.0_EPD_overview_49310.html)?

This is open-source Firmware to support epapers but you need to do your part, research, understand a bit how epdiy works and also help to implement it yourself. Please get some background info in the #256 color support issue and also try to provide more background information about how Kaleido works.
Then if you want to keep on forward with this research we leave this issue open and close the old one. Just opened it so it's more visible in case has something that helps you here.

martinberlin, 2023-11-20:
I suspect the pixel arrangement is very similar to the DES color from Wuxi Weifeng https://en.wf-tech.com/pro_1341.html
so if you have one epdiy board you can try my branch where I'm trying to implement color. But the only function implemented is draw_cpixel (draw color pixel) there is still no GFX functions supporting color.

vanarebane, 2023-11-26:
@martinberlin,
No, I have not yet looked deeper into the color display datasheet. I think I need to get to know some epd basics first.
I'm working on getting myself a copy of epdiy, I was thinking to make a lighter version of the v7, with touch and pwm background also implemented, and right connectors positioned just for what I have in my project.
When I was researching the colour eink display, I believed I could get a cheap second hand Pocketbook Color, but someone was faster than me and purchased it. Then I looked only for a panel separately from [Aliexpress](https://vi.aliexpress.com/item/1005004285847831.html), but it's a bit too pricey for just testing. And I started to doubt if color displays epd-s are good at the moment, as they are too dark. I have PocketBook InkPad Color 7,8" for reading and I almost always have to have backlight on.

My personal project right now is going to be [ED060KC1 with backlight](https://vi.aliexpress.com/item/1005003368019572.html) and some touch-glass, either a too-big 8" with GT911 or see if I'll re-use Kindles 6" touch panel. I just need some touch-enabled-glass that is close to 118mm wide.

TL:DR; Perhaps I can contribute with some PWM backlight support and I2C touch chip support to this project.

martinberlin, 2023-11-26:
Hello @vanarebane

> And I started to doubt if color displays epd-s are good at the moment, as they are too dark. I have PocketBook InkPad Color 7,8" for reading and I almost always have to have backlight on.

Yes that I think happens with all color filters, it has an additional layer on top (or two if touch), and this of course reduces the light. They look all grayish without backlight. I just tested DES from Wuxi Weifeng, sold by Good-Display. Also too expensive for my tests and I just have one.

> Perhaps I can contribute with some PWM backlight support and I2C touch chip support to this project.

About this I think it will be better to collaborate with an LVGL driver. epdiy is really only the epaper component. I don't think @vroland has plans to add touch or backlight support in this repository.
But I know that is possible to use epdiy in LVGL. Please check this repository https://github.com/martinberlin/lv_port_esp32-epaper/ if you are interested in testing. I already added there a GT911 touch driver for LVGL (Really the driver itself is a Espressif component)

vroland, 2023-11-29:
Yes, it looks like lvgl is the way to go for this, it should theoretically already support color / grayscale drawing, touch integration and all that nice stuff...

martinberlin, 2023-12-08:
Thanks for your feedback Valentin.
Wanted to share more insight in supporting color in this display.
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

Started to add the display and it works good with the 34 pin connector. I guess it should work in any board no matter what version is.
But I realized when I tried color that this has a completely different pixel arrangement than color DES. So using the same function to try color comes out all black.

More info: https://github.com/koreader/koreader/issues/6479 in that Issue this interesting guys figured out what is the pixel arrangement. Although I'm starting to realize this color thing is different for each brand and it's actually a pain to handle.
@vroland I'm actually not 100% sure if it's a good idea to integrate it in epdiy or just make it on the outside. Because if we take epdiy as epaper controller and consider the color filter or CFA, like an external addition to the epaper, then there are like 2 different layers. And epdiy is already working great to support the Eink panel below. What I don't really know if we need to really understand how are the CFA setups above, that might change from each fabricant (For now Eink and WF-Tech, but maybe there will be more?)

martinberlin, 2023-12-08:
Advancing slowly with this one. Took me a while to get the color lookup function. Still the colors are way off, but at least they show up. This displays without front light are kind of useless must say, colors look always like a dim pastel (Watercolor painting)
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
(A green field...)
Many adjustments have to be made. Specially would like to see it with front-light

martinberlin, 2023-12-22:
Hello @vanarebane
you asked for this and I accidentally had a Kaleido display coming to my studio and implemented the color. Please check [s3_color_implementation](https://github.com/vroland/epdiy/tree/s3_color_implementation) branch and try it out.
I will only make a Pull request if I see there is real interest on this. And then I will find a display to send Valentin so he can double check it and see if there is any possibility to improve it.

martinberlin, 2024-01-05:
@vanarebane can you check if this works or you?
I'm working on getting one of this Displays and send it to @vroland so we can analyze if there is a way to add color support to epdiy. If there is no feedback or interest anymore in this topic for months then I will close the issue.  I don't like to have issues open forever when there is no feedback since they do not bring anything more than being an open list

vanarebane, 2024-01-05:
@martinberlin sorry for late reply. I missed the notification that you wrote.
As I wrote earlier, I decided to not invest in a colour display because they are too dim.
So for my sake, you can close this topic for now.
Thanks for all the effort, I hope there is some use for colour epds in the future :)

Closed 2024-01-05.

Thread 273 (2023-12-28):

Having issue while compiling the example code for Lilygo T5-4.7

lepeli, 2023-12-28:
Hey, I've tried to compile the example for the Lilygo T5-4.7 and I've runned into some issues.

## Board information

Board: Screen-4.7-S3 V.2.3

## Compilation issue

```
/Users/[redacted]/.platformio/packages/toolchain-xtensa-esp32s3/bin/../lib/gcc/xtensa-esp32s3-elf/8.4.0/../../../../xtensa-esp32s3-elf/bin/ld: .pio/build/t547plus/lib94b/libepdiy.a(epd_board_lilygo_t5_47.c.o):(.literal.epd_board_poweron+0x4): undefined reference to `i2s_gpio_attach'
/Users/[redacted]/.platformio/packages/toolchain-xtensa-esp32s3/bin/../lib/gcc/xtensa-esp32s3-elf/8.4.0/../../../../xtensa-esp32s3-elf/bin/ld: .pio/build/t547plus/lib94b/libepdiy.a(epd_board_lilygo_t5_47.c.o): in function `epd_board_poweron':
/Users/[redacted]/Perso/temp-homescreen/display/.pio/libdeps/t547plus/epdiy/src/board/epd_board_lilygo_t5_47.c:113: undefined reference to `i2s_gpio_attach'
```

For reference my plateformio.ini config looks like this:

```ini
[env:t547plus]
platform = espressif32
upload_protocol = esptool
framework = arduino
upload_speed = 921600
monitor_speed = 115200
board = lilygo-t5-47-plus
build_flags =
	-D CORE_DEBUG_LEVEL=3
        -DCONFIG_EPD_DISPLAY_TYPE_ED047TC1
	-DCONFIG_EPD_BOARD_REVISION_LILYGO_T5_47
lib_deps =
	adafruit/Adafruit GFX Library@^1.11.9
	adafruit/Adafruit BusIO@^1.14.5
	Wire
	SPI
	https://github.com/lewisxhe/PCF8563_Library.git
	bblanchon/ArduinoJson@^6.21.3
	https://github.com/vroland/epdiy.git
```

I didn't get any compilation errors while using the board settings in your plateformio.ini example.
Except that it doesn't want to upload the sketch to the board because of this error:

```
A fatal error occurred: This chip is ESP32-S3 not ESP32. Wrong --chip argument?
```

## EPD_WIDTH and EPD_HEIGHT

```
src/main.cpp: In function 'void display_center_message(const char*)':
src/main.cpp:92:20: error: 'EPD_WIDTH' was not declared in this scope
     int cursor_x = EPD_WIDTH / 2;
                    ^~~~~~~~~
src/main.cpp:93:20: error: 'EPD_HEIGHT' was not declared in this scope
     int cursor_y = EPD_HEIGHT / 2;
```

It seems like theses variables aren't defined by default while using `DCONFIG_EPD_DISPLAY_TYPE_ED047TC1` and `DCONFIG_EPD_BOARD_REVISION_LILYGO_T5_47` build flags.

Thanks in advance for your help :)

martinberlin, 2023-12-28:
This repository does not support the S3 version of Lilygo currently. Please check the current open issue about it:
https://github.com/vroland/epdiy/issues/203

Keep tuned, I have really low hope at this point that this board will be added, because of the facts exposed in that Issue

Closed 2023-12-28.

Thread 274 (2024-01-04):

v7 firmware and the switch to a ESP32-S3 module

second-string, 2024-01-04:
I made a custom PCB that uses epdiy to drive an e-ink display. The only modifications I made [in my fork](https://github.com/vroland/epdiy/compare/master...second-string:epdiy:master) was to switch a pin mapping and disable the RTC sleep for that pin. The esp module I used was an ESP32-WROVER-E with 8MB external flash and 8MB PSRAM.

I can see that the new v7 board is using one of the S3-based modules, switching over to WROOM from WROVER, and going to 16MB flash / 8MB PSRAM.

My question is: are there any underlying firmware changes in the v7 firmware that wouldn't work on a WROVER chip with the same memory specs? I know the S3 is still an Xtensa core and not their RISC-V one, but I'm not sure if there are underlying esp-idf changes or something that would cause the newer repo firmware to not work on a WROVER.

I'd be fine making small tweaks to a fork like I did previously, but would like to avoid a deep dive into the firmware if avoidable. Also I feel like it goes without saying but I also have no problem making hardware changes to the board, part of the reason I'm upgrading the board is to move to a pin expander to free up IO just like the more recent versions of the firmware have.

martinberlin, 2024-01-05:
> there any underlying firmware changes in the v7 firmware that wouldn't work on a WROVER chip with the same memory specs?

The v7 Firmware uses LCD Module internally instead of I2S as it did in the ESP32 WRover version. So you definitely can’t mix one with the other.
But this is resolved and there are precompiler conditionals that will adapt to one tatted or the other.
There are many things that change if you take a deep dive. Sending the pixels is different, the hor. sync and vsync is different, they are two different ways to send the framebuffer. Depending on the target you need to use one method or the other.
V7 using S3 is also faster than ESP32 WRover

second-string, 2024-01-05:
Makes sense. I might lay out two different versions of the board, one for each ESP32 version, as I'd like to use the newer chipset and newer firmware but I'd rather not get stuck on this right now if it doesn't transfer easily.

I can update if I find anything that I need to debug or that isn't know yet. Thanks for the answer!

martinberlin, 2024-01-05:
Sure no problem. With the new boards way to do it that @mickeprag implemented is easier than before to add new custom boards.
Just keep in mind that the easier way to have v7 with S3 working is to stick to the same schematics and signals, meaning to use same IO expander and TPS65185 to drive the voltages. If you do it that way then it should work out of the box provided that the layout is right.

second-string, 2024-01-05:
The switch to the TI TPS6518X chip is the main driver to upgrade this board, it's a cheaper BOM, a simpler layout, and available :)

Closed 2024-01-05.

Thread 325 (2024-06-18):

Implement Wokwi testing

martinberlin, 2024-06-18:
Wokwi is a simulator. The idea is that we could be able to simulate a v7 board, including it's main two chips:

- PCA9535 , I2C 16 bit IO expander, manages eink slow signals
- TPS65185, also talks I2C, generates the needed voltages to drive the pixels (+15 and -15V) plus to open the FET gates that let pass whose (higher ones + VCOM)

First step is to simulate this two as "[Custom chips](https://blog.wokwi.com/custom-chips-cd4051b-analog-multiplexer/)" and attach them to an ESP32S3-DEV board. Then we will simulate the existing v7 board attaching this 2 chips in the I2C line and some LEDs as data output.

If everything turns out as expected, this will simulate that the voltages are on (wokwi does not know about voltages), and we should see how the framebuffer signals are outputted on the data LEDs.
I propose to use different colors:
- Red: Fast signals
- Orange: Slow signals
- Blue: Data in pins

@mickeprag if you are interested on this also you can help out in any way.
This will take many iterations. The end result would be to truly simulate a v7 board, adding an SVG drawing, and the custom chips inside. All this should run picking up the Firmware built from VSCode. At that point it will look and behave as a real board and the idea is that we could try to put this also in the Github CI, so apart of running the tests, it will also try to run the generated Firmware in our "virtual board"

mickeprag, 2024-06-18:
This sounds cool. I am on. Although I have almost zero experience from wokwi...

martinberlin, 2024-06-19:
> This sounds cool. I am on. Although I have almost zero experience from wokwi...

Thanks for your interest. Same here. I'm still figuring out the very basics. For example [here](https://wokwi.com/projects/401153784260252673) I don't have any idea why IO8 does not turn HIGH. Note I'm lazy to put a resistor to each LED but is not that for sure!

mickeprag, 2024-06-19:
Maybe because IO8 is internally connected to the flash?

martinberlin, 2024-06-20:
Ok it was me that I was connecting the wrong pins. The problem with most computer related thing is ourselves except on some rare moments ;)
https://wokwi.com/projects/401153784260252673 -> And next blocker is... that I can't seem to tell the Simulator that the MCU has external RAM. Why I don't know, I'm adding the attribute:

```json
{ "type": "board-esp32-s3-devkitc-1", "id": "esp", "top": -0.18, "left": -5.03,
    "attrs": { "psramSize": "8", "flashSize": "4" }
```

martinberlin, 2024-06-24:
Blocker solved thanks to a hint of Wokwi team:

```json
{
    "type": "board-esp32-s3-devkitc-1",
    "id": "esp",
    "top": -0.18,
    "left": -5.03,
    "attrs": {
        "psramSize": "16",
        "flashSize": "4"
    }
}
```

@vroland and @mickeprag PSRAM is detected now. What remains is to make the 2 mentioned custom chips otherwise the firmware will hang without being able to communicate with the IO expander or the TI Power mic.

martinberlin, 2024-06-25:
Implemented first time custom chip and it seems the CI action works however I still fail to link it on VSCode diagram.json
https://github.com/martinberlin/wokwi-pca9535

martinberlin, 2024-06-26:
@vroland I will need the behaviour of "simulated chip" PCA9535 to be reviewed. What I'm getting in the VSCode console only placing this chip with the pins connected as in v7 Schematic is this:

```
[chip-pca9535] Input mask is now 0xc007
[chip-pca9535] Input mask is now 0x3
[chip-pca9535] Input mask is now 0x2103
[chip-pca9535] Input mask is now 0x2903
[chip-pca9535] Input mask is now 0x3903
[chip-pca9535] Read: reset INT flag
```

Custom chips are not really easy to use. The fastest way that I've found is to make a repository, add some CI, so it get's compiled (output is Web assembly or WASM), and that's how it's loaded into Wokwi. It's a bit of black magic for me, a bit hard to understand, the internals of how all this works together. Hence I need a bit of a review and some help making custom chip TPS65185. On that topic if I understand that right:

To simulate the power Mic I just need to hear on 0x68 address. And when it get's the TPS_REG_ENABLE I2C signal activates the voltages, pulling TPS_PWR_GOOD low. Is that correct?

martinberlin, 2024-07-22:
Advancing very slowly here. In the next days I'm adding the wokwi-tps65185 custom chip.
What it will do really is just to receive the signal to power up the grid and just turn hi a GPIO. It won't really generate any voltages since wokwi does not know anything about volts ;)

vroland, 2024-08-05:
No problem, things are slow during the summer ;) Curious where this goes.

martinberlin, 2024-08-17:
Finished to add new chip:
https://wokwi.com/projects/401153784260252673

Chip itself is in this repository: https://github.com/martinberlin/wokwi-tps65185/
This is just a small wrapper to "emulate" a reply with PWR_GOOD signal since Wokwi does not know about voltages for Eink :electric_plug:
Let's see if I can test it in the next days. Would be cool if someone helps to verify if all connections / signals match the schematic.

vroland, 2024-08-26:
Sounds promising! Did it compile in the end?

martinberlin, 2024-08-26:
No. There must be something in my tps65185 chip that does not like. But I must say that at this point is a bit weird because it can take forever, instead of prompting some kind of useful error message.
My first thoughts where "Ok this is great to make simple simulations" but when going deeper then unexpected things happen, without proper guidance to the developer trying to implement it. Hopefully I'm wrong and it just deserves some more rounds of fight. But I guess you understand what I'm trying to say.

martinberlin, 2025-01-06:
Closing here I tried my best but could not make the TPS65185 simulation work. Might take the idea again when I recover forces from last crash

Closed 2025-01-06.

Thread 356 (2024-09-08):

Crashed when used in conjunction of NimBLE-Arduino + Wi-Fi

rascove, 2024-09-08:
Hi, I'm working on a PlatformIO project that requires the ESP32 (LilyGo T5 4.7) to subscribe and publish to an MQTT broker using Wi-Fi and scan nearby BLE devices, while displaying some data on the e-Paper. I'm using [NimBLE-Arduino](https://github.com/h2zero/nimble-arduino) and built-in Wi-Fi libraries in conjunction with the epdiy.

If I use only two of these libraries (epdiy + Wi-Fi, epdiy + NimBLE-Arduino, or NimBLE-Arduino + Wi-Fi), the project can be successfully executed on the device, however as soon as I added all three libraries at the same time, the device keeps on rebooting. These are the source code, the configuration file, and the log from serial monitor for your reference:

```
#include <Arduino.h>
#include <Epd_Highlevel.h>
#include <Epdiy.h>
#include <FiraSans.h>
#include <NimBLEDevice.h>
#include <WiFi.h>

void setup()
{
	Serial.begin(115200);
	NimBLEDevice::init("");

	NimBLEScan* scanner = NimBLEDevice::getScan();

	scanner->setActiveScan(true);
	WiFi.begin("SSID", "PWD");

	while (WiFi.status() != WL_CONNECTED)
		delay(500);

	epd_init(&epd_board_lilygo_t5_47, &ED047TC1, EPD_LUT_64K);

	EpdiyHighlevelState hl = epd_hl_init(EPD_BUILTIN_WAVEFORM);
	uint8_t* fb = epd_hl_get_framebuffer(&hl);
	int cursor = 0;

	epd_clear();
	epd_write_default(&FiraSans, "Initialising...", &cursor, &cursor, fb);
	epd_poweron();
	epd_hl_update_screen(&hl, MODE_GC16, 27);
	delay(500);
	epd_poweroff();

	NimBLEScanResults foundDevices = scanner->start(10);

	Serial.print("Devices found: ");
	Serial.println(foundDevices.getCount());
}

void loop()
{
}
```

```
[env:esp32dev]
platform = espressif32
board = esp32dev
framework = arduino
board_build.f_cpu = 240000000L
upload_speed = 921600
monitor_speed = 115200
lib_deps =
    https://github.com/vroland/epdiy.git
    h2zero/NimBLE-Arduino
build_flags =
    -DBOARD_HAS_PSRAM
    -DCONFIG_EPD_DISPLAY_TYPE_ED047TC1
    -DCONFIG_EPD_BOARD_REVISION_LILYGO_T5_47
    -DCONFIG_ESP32_WIFI_SW_COEXIST_ENABLE
```

```
rst:0xc (SW_CPU_RESET),boot:0x13 (SPI_FAST_FLASH_BOOT)
configsip: 0, SPIWP:0xee
clk_drv:0x00,q_drv:0x00,d_drv:0x00,cs0_drv:0x00,hd_drv:0x00,wp_drv:0x00
mode:DIO, clock div:2
load:0x3fff0030,len:1184
load:0x40078000,len:13232
load:0x40080400,len:3028
entry 0x400805e4

assert failed: epd_hl_init highlevel.c:50 (state.dirty_columns != NULL)

Backtrace: 0x40084ae1:0x3ffcd210 0x40096a6d:0x3ffcd230 0x4009cbdd:0x3ffcd250 0x400d356f:0x3ffcd380 0x400d2aee:0x3ffcd3b0 0x400e8c5e:0x3ffcd430
```

Thank you very much in advance.

martinberlin, 2024-09-10:
Hi @rascove

> I'm working on a PlatformIO project that requires the ESP32 (LilyGo T5 4.7)

You will be much better off writing an issue in [their Repository](https://github.com/Xinyuan-LilyGO/LilyGo-EPD47/). Because we do not produce this Hardware and not even their code which is based on epdiy v2 ( And as you can see here the PCB is already version 7 )

You could try the same code in a different hardware maybe. And also make some tests with the latest version of the Firmware of this repository.

rascove, 2024-09-10:
Thanks for the feedback @martinberlin , I'll do that as well.

I'm posting this here because the error is caused when the `EpdiyHighlevelState` is being initialised, as shown in the serial log: `assert failed: epd_hl_init highlevel.c:50 (state.dirty_columns != NULL)`.

Anyway, thank you very much and have a great day ahead.

martinberlin, 2024-09-10:
Sure, but you are using a library that is from Lilygo and since long time updated here.
If you switch to this repository with the latest library then esp32 version of Lilygo is still supported. (Not S3)
Anyways buying a product from Lilygo is the hardware provider who should give support.

rascove, 2024-09-11:
Hi @martinberlin , thanks for the response but please refer to my code and PlatformIO configuration. I'm not using LilyGo T5 library at all, in fact, I'm using [this repository's own example](https://github.com/vroland/epdiy/tree/main/examples/lilygo-t5-47-epd-platformio) to build the project.

martinberlin, 2024-09-11:
Don't really understand why then:

#include <Epd_Highlevel.h>
#include <Epdiy.h>

Use first letter uppercase. The example code in this repositories are not like this and it won't find the include if you uppercase first letter.
I will try when I find sometime your code, but I need to find my Lilygo first. I highly recommend you to switching to a v7 board though, to use the latest code using LCD Module. I've still one v7 unit available in tindie.com if you search for "epdiy"

rascove, 2024-09-11:
Ah, I'm so sorry about that. I'm using Windows so the filename is not case-sensitive, and coming from Java background, it's my habit to capitalise the first letter of the library.

But thank you very much for your kind assistance, @martinberlin , I really appreciate that. Unfortunately I don't have a control for the type of e-Paper used as it was purchased by the client.

martinberlin, 2024-09-11:
Also this line of the assert where it stops:

    state.dirty_columns
        = heap_caps_aligned_alloc(16, epd_width() / 2, MALLOC_CAP_INTERNAL | MALLOC_CAP_8BIT);

Creates the RAM space. If it's not allocated then the assert will fail. Try to locate it in PSRAM, but that will be slower, and not sure if it will work. It might be that using this combination of libraries won't work with the hardware.
That's why I was suggesting to update to v7. You will need to deep debug this and check how much Heap RAM you have available, I guess this could be the most probable cause.

rascove, 2024-09-14:
Hi @martinberlin ,

Sorry for the late response and thank you very much for your advice about the insufficient RAM. It gave me the idea to initialise the BLE stack in the PSRAM instead, which is already provided by the NimBLE-Arduino library. And now, all three libraries can be used altogether.

Once again, thank you very much and have a great day ahead.

Closed 2024-09-10.

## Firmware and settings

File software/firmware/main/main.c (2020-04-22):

/* Simple firmware for a ESP32 displaying a static image on an EPaper Screen.
 *
 * Write an image into a header file using a 3...2...1...0 format per pixel,
 * for 4 bits color (16 colors - well, greys.) MSB first.  At 80 MHz, screen
 * clears execute in 1.075 seconds and images are drawn in 1.531 seconds.
 */

#include "esp_heap_caps.h"
#include "esp_log.h"
#include "esp_timer.h"
#include "esp_types.h"
#include "freertos/FreeRTOS.h"
#include "freertos/task.h"
#include "sdkconfig.h"
#include <stdio.h>
#include <string.h>

#include "epd_driver.h"
#ifdef CONFIG_EPD_DISPLAY_TYPE_ED060SC4
#include "firasans_12pt.h"
#else
#include "firasans.h"
#endif
#include "giraffe.h"
#include "image.h"
#include "img_board.h"

uint8_t *img_buf;

uint8_t *framebuffer;
uint8_t *original_image_ram;

void delay(uint32_t millis) { vTaskDelay(millis / portTICK_PERIOD_MS); }

uint32_t millis() { return esp_timer_get_time() / 1000; }

void loop() {

  printf("current temperature: %f\n", epd_ambient_temperature());
  delay(300);
  epd_poweron();


  volatile uint32_t t1 = millis();
  epd_clear();
  volatile uint32_t t2 = millis();
  printf("EPD clear took %dms.\n", t2 - t1);

  epd_draw_hline(20, 20, EPD_WIDTH - 40, 0x00, framebuffer);
  epd_draw_hline(20, EPD_HEIGHT - 20, EPD_WIDTH - 40, 0x00, framebuffer);
  epd_draw_vline(20, 20, EPD_HEIGHT - 40 + 1, 0x00, framebuffer);
  epd_draw_vline(EPD_WIDTH - 20, 20, EPD_HEIGHT - 40 + 1, 0x00, framebuffer);

  Rect_t area = {
      .x = 25,
      .y = 25,
      .width = giraffe_width,
      .height = giraffe_height,
  };
  epd_copy_to_framebuffer(area, (uint8_t *)giraffe_data, framebuffer);

#ifdef CONFIG_EPD_DISPLAY_TYPE_ED060SC4
  int cursor_x = 20 + giraffe_width + 20;
#else
  int cursor_x = 50 + giraffe_width + 20;
#endif
  int cursor_y = 100;
  write_string((GFXfont *)&FiraSans,
        "➸ 16 color grayscale\n"
        "➸ ~630ms for full frame draw 🚀\n"
        "➸ Use with 6\" or 9.7\" EPDs\n"
        "➸ High-quality font rendering ✎🙋",
  &cursor_x, &cursor_y, framebuffer);

  t1 = millis();
  epd_draw_grayscale_image(epd_full_screen(), framebuffer);
  t2 = millis();
  printf("EPD draw took %dms.\n", t2 - t1);

  delay(1000);
  cursor_x = 500;
#ifdef CONFIG_EPD_DISPLAY_TYPE_ED060SC4
  cursor_y = 450;
#else
  cursor_y = 600;
#endif
  char *string = "➠ With partial clear...";
  writeln((GFXfont *)&FiraSans, string, &cursor_x, &cursor_y, NULL);

  delay(1000);

  Rect_t to_clear = {
      .x = 50 + giraffe_width + 20,
#ifdef CONFIG_EPD_DISPLAY_TYPE_ED060SC4
  .y = 300,
#else
  .y = 400,
#endif
      .width = EPD_WIDTH - 70 - 25 - giraffe_width,
      .height = 400,
  };
  epd_clear_area(to_clear);

  cursor_x = 500;
  cursor_y = 390;
  string = "And partial update!";
  writeln((GFXfont *)&FiraSans, string, &cursor_x, &cursor_y, NULL);

  Rect_t board_area = {
      .x = 50 + giraffe_width + 50,
#ifdef CONFIG_EPD_DISPLAY_TYPE_ED060SC4
  .y = 300,
#else
  .y = 400,
#endif
      .width = img_board_width,
      .height = img_board_height,
  };

  epd_draw_grayscale_image(board_area, (uint8_t*)img_board_data);
  epd_poweroff();

  delay(2000);
}

void epd_task() {
  epd_init();

  ESP_LOGW("main", "allocating...\n");

  original_image_ram =
      (uint8_t *)heap_caps_malloc(EPD_WIDTH * EPD_HEIGHT / 2, MALLOC_CAP_SPIRAM);
  framebuffer = (uint8_t *)heap_caps_malloc(EPD_WIDTH * EPD_HEIGHT / 2, MALLOC_CAP_SPIRAM);
  memset(framebuffer, 0xFF, EPD_WIDTH * EPD_HEIGHT / 2);

  volatile uint32_t t = millis();
  memcpy(original_image_ram, img_bytes, EPD_WIDTH * EPD_HEIGHT / 2);
  volatile uint32_t t2 = millis();
  printf("original copy to PSRAM took %dms.\n", t2 - t);

  while (1) {
    loop();
  };
}

void app_main() {
  ESP_LOGW("main", "Hello World!\n");

  heap_caps_print_heap_info(MALLOC_CAP_INTERNAL);
  heap_caps_print_heap_info(MALLOC_CAP_SPIRAM);

  xTaskCreatePinnedToCore(&epd_task, "epd task", 10000, NULL, 2, NULL, 1);
}

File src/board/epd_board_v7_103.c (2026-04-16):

#include <stdint.h>
#include "epd_board.h"
#include "epdiy.h"

#include "../output_common/render_method.h"
#include "../output_lcd/lcd_driver.h"
#include "esp_log.h"
#include "epd_board_i2c.h"
#include "pca9555.h"
#include "tps65185.h"

#include <driver/gpio.h>
#include <sdkconfig.h>

#include <freertos/FreeRTOS.h>
#include <freertos/task.h>

#include <stdio.h>

// Make this compile von the ESP32 without ifdefing the whole file
#ifndef CONFIG_IDF_TARGET_ESP32S3
#define GPIO_NUM_40 -1
#define GPIO_NUM_41 -1
#define GPIO_NUM_42 -1
#define GPIO_NUM_43 -1
#define GPIO_NUM_44 -1
#define GPIO_NUM_45 -1
#define GPIO_NUM_46 -1
#define GPIO_NUM_47 -1
#define GPIO_NUM_48 -1
#endif

#define CFG_SCL GPIO_NUM_40
#define CFG_SDA GPIO_NUM_39
#define CFG_INTR GPIO_NUM_2  // NUM_2 is >1.1    NUM_38 is 1.0

#define CFG_PIN_OE (PCA_PIN_PC10 >> 8)
#define CFG_PIN_MODE (PCA_PIN_PC11 >> 8)
#define __CFG_PIN_STV (PCA_PIN_PC12 >> 8)
#define CFG_PIN_PWRUP (PCA_PIN_PC13 >> 8)
#define CFG_PIN_VCOM_CTRL (PCA_PIN_PC14 >> 8)
#define CFG_PIN_WAKEUP (PCA_PIN_PC15 >> 8)
#define CFG_PIN_PWRGOOD (PCA_PIN_PC16 >> 8)
#define CFG_PIN_INT (PCA_PIN_PC17 >> 8)

#define D15 GPIO_NUM_5
#define D14 GPIO_NUM_6
#define D13 GPIO_NUM_7
#define D12 GPIO_NUM_15
#define D11 GPIO_NUM_16
#define D10 GPIO_NUM_17
#define D9 GPIO_NUM_18
#define D8 GPIO_NUM_8

#define D7 GPIO_NUM_9
#define D6 GPIO_NUM_10
#define D5 GPIO_NUM_11
#define D4 GPIO_NUM_12
#define D3 GPIO_NUM_13
#define D2 GPIO_NUM_14
#define D1 GPIO_NUM_21
#define D0 GPIO_NUM_47

/* Control Lines */
#define CKV GPIO_NUM_42
#define STH GPIO_NUM_45
#define LEH GPIO_NUM_48
#define STV GPIO_NUM_41

/* Edges */
#define CKH GPIO_NUM_4

typedef struct {
    epd_board_i2c_context_t i2c;
    bool pwrup;
    bool vcom_ctrl;
    bool wakeup;
    bool others[8];
} epd_config_register_t;

static const epd_board_i2c_bus_config_t board_i2c_config = {
    .port = I2C_NUM_0,
    .sda_io_num = CFG_SDA,
    .scl_io_num = CFG_SCL,
    .bus_speed_hz = 100000,
};

/** The VCOM voltage to use. */
static int vcom = 1600;

static epd_config_register_t config_reg;

static bool interrupt_done = false;

static void IRAM_ATTR interrupt_handler(void* arg) {
    interrupt_done = true;
}

static lcd_bus_config_t lcd_config = {
    .clock = CKH,
    .ckv = CKV,
    .leh = LEH,
    .start_pulse = STH,
    .stv = STV,
    .data[0] = D0,
    .data[1] = D1,
    .data[2] = D2,
    .data[3] = D3,
    .data[4] = D4,
    .data[5] = D5,
    .data[6] = D6,
    .data[7] = D7,
    .data[8] = D8,
    .data[9] = D9,
    .data[10] = D10,
    .data[11] = D11,
    .data[12] = D12,
    .data[13] = D13,
    .data[14] = D14,
    .data[15] = D15,
};

static void epd_board_init(uint32_t epd_row_width, const EpdInitConfig* init_config) {
    gpio_hold_dis(CKH);  // free CKH after wakeup

    ESP_ERROR_CHECK(epd_board_i2c_init(&config_reg.i2c, &board_i2c_config, init_config, true, true)
    );
    config_reg.pwrup = false;
    config_reg.vcom_ctrl = false;
    config_reg.wakeup = false;
    for (int i = 0; i < 8; i++) {
        config_reg.others[i] = false;
    }

    gpio_set_direction(CFG_INTR, GPIO_MODE_INPUT);
    gpio_set_intr_type(CFG_INTR, GPIO_INTR_NEGEDGE);

    ESP_ERROR_CHECK(gpio_install_isr_service(ESP_INTR_FLAG_EDGE));

    ESP_ERROR_CHECK(gpio_isr_handler_add(CFG_INTR, interrupt_handler, (void*)CFG_INTR));

    // set all epdiy lines to output except TPS interrupt + PWR good
    ESP_ERROR_CHECK(pca9555_set_config(config_reg.i2c.pca, CFG_PIN_PWRGOOD | CFG_PIN_INT, 1));

    const EpdDisplay_t* display = epd_get_display();

    LcdEpdConfig_t config = {
        .pixel_clock = display->bus_speed * 1000 * 1000,
        .ckv_high_time = 60,
        .line_front_porch = 4,
        .le_high_time = 4,
        .bus_width = display->bus_width,
        .bus = lcd_config,
    };
    epd_lcd_init(&config, display->width, display->height);
}

static void epd_board_deinit() {
    epd_lcd_deinit();

    ESP_ERROR_CHECK(pca9555_set_config(
        config_reg.i2c.pca, CFG_PIN_PWRGOOD | CFG_PIN_INT | CFG_PIN_VCOM_CTRL | CFG_PIN_PWRUP, 1
    ));

    int tries = 0;
    while (!((pca9555_read_input(config_reg.i2c.pca, 1) & 0xC0) == 0x80)) {
        if (tries >= 50) {
            ESP_LOGE("epdiy", "failed to shut down TPS65185!");
            break;
        }
        tries++;
        vTaskDelay(1);
    }

    // Not sure why we need this delay, but the TPS65185 seems to generate an interrupt after some
    // time that needs to be cleared.
    vTaskDelay(50);
    pca9555_read_input(config_reg.i2c.pca, 0);
    pca9555_read_input(config_reg.i2c.pca, 1);
    epd_board_i2c_deinit(&config_reg.i2c);

    gpio_uninstall_isr_service();
}
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

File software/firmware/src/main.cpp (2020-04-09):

/* Simple firmware for a ESP32 displaying a static image on an EPaper Screen.
 *
 * Write an image into a header file using a 3...2...1...0 format per pixel,
 * for 4 bits color (16 colors - well, greys.) MSB first.  At 80 MHz, screen
 * clears execute in 1.075 seconds and images are drawn in 1.531 seconds.
 */
#include "Arduino.h"

extern "C" {
#include "EPD.h"
#include "firasans.h"
#include "font.h"
#include "image.h"
}

/* Display State Machine */
enum ScreenState {
  CLEAR_SCREEN = 0,
  DRAW_SCREEN = 1,
  CLEAR_PARTIAL = 2,
  DRAW_SQUARES = 3,
};

uint8_t *img_buf;

void setup() {
  Serial.begin(115200);
  epd_init();

  img_buf = (uint8_t *)heap_caps_malloc(1200 * 825 * 2, MALLOC_CAP_SPIRAM);
  volatile uint32_t t = micros();
  img_8bit_to_unary_image(img_buf, (uint8_t*)img_bytes, 1200, 825);
  volatile uint32_t t2 = micros();
  printf("copy to PSRAM took %d us.\n", t2 - t);

  heap_caps_print_heap_info(MALLOC_CAP_INTERNAL);
  heap_caps_print_heap_info(MALLOC_CAP_SPIRAM);
}

void loop() {
  // Variables to set one time.
  static ScreenState _state = CLEAR_SCREEN;

  delay(300);
  epd_poweron();

  uint32_t timestamp = 0;
  if (_state == CLEAR_SCREEN) {
    Serial.println("Clear cycle.");
    Serial.flush();
    timestamp = millis();
    epd_clear();
    _state = DRAW_SCREEN;

  } else if (_state == DRAW_SCREEN) {
    Serial.println("Draw cycle.");
    timestamp = millis();
    draw_image_unary_coded(epd_full_screen(), img_buf);
    _state = CLEAR_PARTIAL;

  } else if (_state == CLEAR_PARTIAL) {
    Serial.println("Partial clear cycle.");
    timestamp = millis();
    Rect_t area = {
        .x = 100,
        .y = 100,
        .width = 1200 - 200,
        .height = 825 - 200,
    };
    epd_clear_area(area);
    _state = DRAW_SQUARES;
  } else if (_state == DRAW_SQUARES) {
    Serial.println("Squares cycle.");
    timestamp = millis();
    int cursor_x = 100;
    int cursor_y = 200;
    unsigned char *string = (unsigned char *)"Hello World! *g*";
    writeln((GFXfont *)&FiraSans, string, &cursor_x, &cursor_y);
    cursor_y += FiraSans.advance_y;
    string = (unsigned char *)"äöüßabcd/#{🚀";
    writeln((GFXfont *)&FiraSans, string, &cursor_x, &cursor_y);
    _state = CLEAR_SCREEN;
  }
  epd_poweroff();
  // Print out the benchmark
  timestamp = millis() - timestamp;
  Serial.print("Took ");
  Serial.print(timestamp);
  Serial.println(" ms to redraw the screen.");

  // Wait 4 seconds then do it again
  delay(2000);
  Serial.println("Going active again.");
}

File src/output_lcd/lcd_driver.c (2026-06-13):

#include "lcd_driver.h"
#include "epdiy.h"

#include "../output_common/render_method.h"
#include "../output_common/rmt_compat.h"
#include "esp_heap_caps.h"
#include "esp_intr_alloc.h"
#include "hal/gpio_types.h"

#ifdef RENDER_METHOD_LCD

#include <assert.h>
#include <esp_idf_version.h>
#include <esp_log.h>
#include <stddef.h>
#include <stdint.h>
#include <string.h>

#include <esp_private/periph_ctrl.h>
#include <soc/clk_tree_defs.h>

#include <driver/gpio.h>
#include <esp_check.h>
#include <esp_err.h>
#include <esp_lcd_panel_ops.h>
#include <esp_lcd_panel_rgb.h>
#include <esp_private/gdma.h>
#include <esp_timer.h>
#include <freertos/FreeRTOS.h>
#include <freertos/semphr.h>
#include <freertos/task.h>
#include <hal/dma_types.h>
#include <hal/gdma_ll.h>
#include <hal/gpio_hal.h>
#include <hal/lcd_hal.h>
#include <hal/lcd_ll.h>
#if ESP_IDF_VERSION >= ESP_IDF_VERSION_VAL(6, 0, 0)
#if __has_include(<rom/cache.h>)
#include <rom/cache.h>
#elif __has_include(<esp32s3/rom/cache.h>)
#include <esp32s3/rom/cache.h>
#endif
typedef struct {
    const shared_periph_module_t module;
    const int irq_id;
    const int data_sigs[LCD_LL_GET(RGB_BUS_WIDTH)];
    const int hsync_sig;
    const int vsync_sig;
    const int pclk_sig;
    const int de_sig;
    const int disp_sig;
} soc_lcd_rgb_signal_desc_t;
extern const soc_lcd_rgb_signal_desc_t soc_lcd_rgb_signals[LCD_LL_GET(RGB_PANEL_NUM)];
#else
#include <rom/cache.h>
#include <soc/lcd_periph.h>
#endif

#include "hal/gpio_hal.h"

gpio_hal_context_t hal = { .dev = GPIO_HAL_GET_HW(GPIO_PORT_0) };

#if ESP_IDF_VERSION >= ESP_IDF_VERSION_VAL(5, 5, 0)
#undef __DECLARE_RCC_ATOMIC_ENV
#endif

#define TAG "epdiy"

// In IDF 5.3.2+, lcd_periph_signals was renamed to lcd_periph_rgb_signals
#if ESP_IDF_VERSION >= ESP_IDF_VERSION_VAL(6, 0, 0)
#define LCD_PERIPH_SIG(member) soc_lcd_rgb_signals[0].member
#elif ESP_IDF_VERSION >= ESP_IDF_VERSION_VAL(5, 3, 2)
#define LCD_PERIPH_SIG(member) lcd_periph_rgb_signals.panels[0].member
#else
#define LCD_PERIPH_SIG(member) lcd_periph_signals.panels[0].member
#endif

static inline int min(int x, int y) {
    return x < y ? x : y;
}
static inline int max(int x, int y) {
    return x > y ? x : y;
}

#define S3_LCD_PIN_NUM_BK_LIGHT -1
// #define S3_LCD_PIN_NUM_MODE           4

#define LINE_BATCH 1000
#define BOUNCE_BUF_LINES 4

#define RMT_CKV_CHAN RMT_COMPAT_CHANNEL_1

#if defined(CONFIG_ESP32S3_DATA_CACHE_LINE_SIZE)
#define EPDIY_DATA_CACHE_LINE_SIZE CONFIG_ESP32S3_DATA_CACHE_LINE_SIZE
#elif defined(CONFIG_DATA_CACHE_LINE_SIZE)
#define EPDIY_DATA_CACHE_LINE_SIZE CONFIG_DATA_CACHE_LINE_SIZE
#else
#define EPDIY_DATA_CACHE_LINE_SIZE 64
#endif

// spinlock for protecting the critical section at frame start
static portMUX_TYPE frame_start_spinlock = portMUX_INITIALIZER_UNLOCKED;

typedef struct {
    lcd_hal_context_t hal;
    intr_handle_t vsync_intr;
    intr_handle_t done_intr;

    frame_done_func_t frame_done_cb;
    line_cb_func_t line_source_cb;
    void* line_cb_payload;
    void* frame_cb_payload;

    int line_length_us;
    int line_cycles;
    int lcd_res_h;

    LcdEpdConfig_t config;

    uint8_t* bounce_buffer[2];
    // size of a single bounce buffer
    size_t bb_size;
    size_t bb_eof_count;
    size_t batches;

    // Number of DMA descriptors that used to carry the frame buffer
    size_t num_dma_nodes;
    // DMA channel handle
    gdma_channel_handle_t dma_chan;
    // DMA descriptors pool
    dma_descriptor_t* dma_nodes;

    /// The number of bytes in a horizontal display register line.
    int line_bytes;

    // With 8 bit bus width, we need a dummy cycle before the actual data,
    // because the LCD peripheral behaves weirdly.
    // Also see:
    // https://blog.adafruit.com/2022/06/14/esp32uesday-hacking-the-esp32-s3-lcd-peripheral/
    int dummy_bytes;

    /// The number of lines of the display
    int display_lines;
} s3_lcd_t;

static s3_lcd_t lcd = { 0 };

void IRAM_ATTR epd_lcd_line_source_cb(line_cb_func_t line_source, void* payload) {
    lcd.line_source_cb = line_source;
    lcd.line_cb_payload = payload;
}

void IRAM_ATTR epd_lcd_frame_done_cb(frame_done_func_t cb, void* payload) {
    lcd.frame_done_cb = cb;
    lcd.frame_cb_payload = payload;
}

static IRAM_ATTR bool fill_bounce_buffer(uint8_t* buffer) {
    bool task_awoken = false;

    for (int i = 0; i < BOUNCE_BUF_LINES; i++) {
        if (lcd.line_source_cb != NULL) {
            // this is strange, with 16 bit need a dummy cycle. But still, the first byte in the
            // FIFO is correct. So we only need a true dummy byte in the FIFO in the 8 bit
            // configuration.
            int buffer_offset = i * (lcd.line_bytes + lcd.dummy_bytes) + lcd.dummy_bytes;
            task_awoken |= lcd.line_source_cb(lcd.line_cb_payload, &buffer[buffer_offset]);
        } else {
            memset(&buffer[i * lcd.line_bytes], 0x00, lcd.line_bytes);
        }
    }
    return task_awoken;
}

static void IRAM_ATTR start_ckv_cycles(int cycles) {
    rmt_compat_tx_configure_finite_loop(RMT_CKV_CHAN, cycles);
    rmt_compat_tx_reset_mem(RMT_CKV_CHAN);
    rmt_compat_tx_start(RMT_CKV_CHAN);
}

/**
 * Build the RMT signal according to the timing set in the lcd object.
 */
static void ckv_rmt_build_signal() {
    int low_time = (lcd.line_length_us * 10 - lcd.config.ckv_high_time);
    rmt_compat_write_single_item(
        RMT_CKV_CHAN, lcd.config.ckv_high_time, true, low_time, false, true
    );
}

/**
 * Configure the RMT peripheral for use as the CKV clock.
 */
static void init_ckv_rmt() {
    rmt_compat_reset_module();
    rmt_compat_enable_module(true);

    rmt_compat_enable_periph_clock(true);
    rmt_compat_set_group_clock_src(RMT_CKV_CHAN);
    rmt_compat_set_clock_div(RMT_CKV_CHAN, 8);
    rmt_compat_set_mem_blocks(RMT_CKV_CHAN, 2);
    rmt_compat_enable_mem_access_nonfifo(true);
    rmt_compat_tx_set_idle_level(RMT_CKV_CHAN, 0, true);
    rmt_compat_tx_enable_carrier(RMT_CKV_CHAN, false);
    rmt_compat_tx_enable_loop(RMT_CKV_CHAN, true);

    rmt_compat_connect_gpio(RMT_CKV_CHAN, lcd.config.bus.ckv);

    ckv_rmt_build_signal();
}

/**
 * Reset the CKV RMT configuration.
 */
static void deinit_ckv_rmt() {
    rmt_compat_reset_module();
    rmt_compat_enable_periph_clock(false);
    rmt_compat_enable_module(false);
    gpio_reset_pin(lcd.config.bus.ckv);
}
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

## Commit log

2019-09-06 uart connection
    [epaper-breakout.sch]
2019-09-06 properly connect micro USB
    [epaper-breakout.sch]
2019-09-08 ESP32 wiring
    [epaper-breakout.sch]
2019-09-10 common voltage generation
    [epaper-breakout.sch]
2019-09-10 reset esp32 manualy
    [epaper-breakout.sch]
2019-09-10 add debug breakout
    [epaper-breakout.sch]
2019-09-11 add footprints for usb, switches, potentiometer
    [epaper-breakout.sch]
2019-09-13 first pcb component clustering
    [epaper-breakout.kicad_pcb, epaper-breakout.sch]
2019-09-14 fpc connector wiring
    [epaper-breakout.kicad_pcb]
2019-09-14 initial wiring
    [epaper-breakout.kicad_pcb]
2019-09-14 fix drc problems
    [epaper-breakout.kicad_pcb]
2019-09-14 add screw holes
    [epaper-breakout.kicad_pcb]
2019-09-14 copper pour and ground connections
    [epaper-breakout.kicad_pcb]
2019-09-15 add silk hints
    [epaper-breakout.kicad_pcb]
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2019-10-04 lower capacity of C15
    [epaper-breakout.sch]
2019-10-04 fix weird fill near u2
    [epaper-breakout.kicad_pcb]
2019-10-04 move C15,C18 closer to ESP power
    [epaper-breakout.kicad_pcb]
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2019-11-01 add lcsc bom for reference
    [bom_LCSC.csv]
2019-12-08 replace display dimension properties with defines
    This actually improves performance significantly by
    making the display dimensions available at compile time.
    [main.cpp]
2019-12-08 fix rendering of partial frame buffers
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2019-12-13 fix fifo order for 2bpp output
    [main.cpp]
2020-03-07 change to wrover module
    [epaper-breakout.sch]
2020-03-11 add second connector, temperature sensor
    [epaper-breakout.sch]
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2020-03-20 move pcb on workspace
    [epaper-breakout.kicad_pcb]
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2020-04-07 avoid unnecessary waiting when switching buffers
    [i2s_data_bus.c]
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2020-04-11 move to esp-idf framework
    [partitions_larger_singleapp.csv]
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2020-04-18 fix i2s double buffering
    [i2s_data_bus.c]
2020-04-18 fix buffer swap when skipping
    [i2s_data_bus.c]
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2020-04-21 fix buffer switching condition
    [i2s_data_bus.c]
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2020-04-24 move demo project to examples
    [partitions_larger_singleapp.csv]
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2020-05-06 terminal: fix text buffer bounds
    [main.c]
2020-05-17 Revert "wip: change_image"
    This reverts commit a8366e2a442ea7ecd4fa30b8ad94d3ec9f7d497f.
    [i2s_data_bus.c]
2020-05-28 updated pdfs and gerbers
    [epaper-breakout-B_Cu.gbr, epaper-breakout-B_Mask.gbr, epaper-breakout-B_Paste.gbr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]
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2020-05-28 Revert "also made new gerbers.zip file"
    This reverts commit 95a55990c93174933f824186796164e53a116d6a.
2020-05-28 added 5v/3v jumper for LT1945. Also redid a ton of ground vias for better ground plane connection
    [epaper-breakout.kicad_pcb, epaper-breakout.sch]
2020-05-28 update PDF and gerbers for my upgrades
    [epaper-breakout-B_Cu.gbr, epaper-breakout-B_Mask.gbr, epaper-breakout-B_Paste.gbr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]
2020-05-28 add notes on board versions in readme
    [bom_jlcpcb.csv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]
2020-05-28 move vias for larger clearances
    [epaper-breakout.kicad_pcb]
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2020-05-28 unused opamp should be neutralized
    [epaper-breakout.kicad_pcb, epaper-breakout.sch]
2020-05-29 add complete BOM (fix #4)
    [BOM.csv]
2020-05-30 mountingholes are back! (might be slightly misalinged with previous iterations
    [epaper-breakout.kicad_pcb, epaper-breakout.sch]
2020-05-30 added VCOM testpad and silkscreen
    [epaper-breakout.kicad_pcb, epaper-breakout.sch]
2020-05-30 added 3d models, cheated a bit on the potentiometer
    [FH12-33S-0.5SH.stp, S3B-PH-SM4-TB.stp, Tactal Switch - SMD (5mmx 5mmx1.5mm).stp]
2020-05-30 forgot the pcb and cache
    [epaper-breakout.kicad_pcb]
2020-05-30 hide the silkscreen for the mounting holes
    [epaper-breakout.kicad_pcb]
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2020-06-02 adjust relative position of mounting holes
    [epaper-breakout.kicad_pcb]
2020-06-03 Fixed value R14 to 390k as 400k doesnt exist and it will work anyway
    [epaper-breakout.kicad_pcb, epaper-breakout.sch]
2020-06-04 added label with pin numbers for pinheader
    [epaper-breakout.kicad_pcb]
2020-06-25 update gerber files (#14)
    [epaper-breakout-B_Cu.gbr, epaper-breakout-B_Mask.gbr, epaper-breakout-B_Paste.gbr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]
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2020-07-01 dont't wait after skipping.
    Rather, it is needed to wait before drawing the next frame if
    the draw cycle was very short.
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2020-07-07 EPD driver: added support of ED097OC4 with 1/3 issue (call it low quality display)
    [i2s_data_bus.c]
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2020-07-24 add ed133ut2 connector to KiCad lib
    [epaper-breakout.csv, partlist.ods]
2020-07-25 add extension cable pcb
    [extension-cable.kicad_pcb, extension-cable.sch]
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2020-09-01 complete designators in BOM
    [BOM.csv]
2020-09-01 add lcsc part number to symbols
    [epaper-breakout.sch]
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2020-10-28 add preliminary 3rd hardware revision
    *This is currently untested!*
    A new revision of the hardware, reducing power consumption.
    [epaper-breakout-B_Cu.gbr, epaper-breakout-B_Mask.gbr, epaper-breakout-B_Paste.gbr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]
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2020-10-28 add 3d models for coils
    [epaper-breakout.kicad_pcb]
2020-10-28 add lcsc part numbers
    [epaper-breakout.sch]
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2020-10-28 renamve to v4 to differentiate from improved v2
    [epaper-breakout.kicad_pcb]
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2020-11-15 mpd: more robust error handling
    [main.c]
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2021-01-04 mpd: error handling on empty queue
    [main.c]
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2021-01-06 change board license to CC-BY-SA 4.0 (#31)
    [epaper-breakout.sch]
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2021-01-25 v5: use ch340g with auto-reset
    [epaper-breakout.sch]
2021-01-25 xc5 connector, power management
    [epaper-breakout.sch]
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2021-01-25 v5: lipo charger circuit
    [epaper-breakout.sch]
2021-01-25 v5 fix pin functions
    [epaper-breakout.sch]
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2021-01-25 remove battery protection, simplify
    [epaper-breakout.kicad_pcb, epaper-breakout.sch]
2021-01-25 add battery voltage sensing, routing
    [epaper-breakout.kicad_pcb, epaper-breakout.sch]
2021-01-25 add decoupling cap to battery voltage sensor
    [epaper-breakout.kicad_pcb, epaper-breakout.sch]
2021-01-25 v5: swap gpio 0 and 19
    [epaper-breakout.kicad_pcb, epaper-breakout.sch]
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2021-01-25 v5: fix mosfet orientation
    [BOM.csv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]
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2021-01-31 Update main.c
    Fix
    vrolandAPP 6:02 PM
    Nice catch, that's a classic overflow right here! esp_timer_get_time() returns an int64_t, but t_poweron is uint32_t. So, after 2^32/10^6/60 = 71.5 min = 1 hour 11 minutes t_poweron overflows and time_since_poweron_m will be > 10. Changing the time of t_poweron to int64_t should fix it :)
    [main.c]
2021-02-03 Adjust solderpaste after JLCPCB feedback
    [epaper-breakout-B_Cu.gbr, epaper-breakout-B_Mask.gbr, epaper-breakout-B_Paste.gbr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]
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2021-02-19 use long frametime to prevent ghost lines
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2021-03-12 fix highlevel framebuffer size
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2021-03-24 correct vendor waveform frame time
2021-03-25 fix demo for small displays
    [main.c]
2021-03-25 Update include path to the right file. REF: https://github.com/vroland/epdiy/issues/58
    [main.c]
2021-03-25 Add software rotation in epd_draw_pixel REF https://github.com/vroland/epdiy/issues/71
    [main.c]
2021-03-25 Adding font rotation. Suggested correction REF https://github.com/vroland/epdiy/issues/71
    [main.c]
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2021-03-28 Rotation on partial update: Working correctly for 0 and 2 (inverted landscape) REF https://github.com/vroland/epdiy/issues/71
    [main.c]
2021-03-29 Add epd_rotated_display_width() + epd_rotated_display_height() and implement them in examples/demo REF https://github.com/vroland/epdiy/issues/71
    [main.c]
2021-03-29 Add epd_get_pixel function and update demo to work with rotated images REF https://github.com/vroland/epdiy/issues/71
    [main.c]
2021-04-01 Move _rotated_area out of public header REF https://github.com/vroland/epdiy/issues/71
    [main.c]
2021-04-01 Add new enum EpdRotation REF https://github.com/vroland/epdiy/issues/71
    [main.c]
2021-04-10 Cleanup examples/demo. Leave grayscale example unchanged REF https://github.com/vroland/epdiy/issues/71
    [main.c]
2021-04-10 Use enum or display_rotation. Handle all switch cases also using this REF https://github.com/vroland/epdiy/issues/71
2021-04-10 Solve EPD_ROT_LANDSCAPE not handled in switch (highlevel.c:60). Update types mentioned by @vroland for epd_rotated_display_* functions REF https://github.com/vroland/epdiy/issues/71
2021-04-13 Fix bug when pressing up and down
    Bug found when scrolling using up and down in recent linux command history
    vroland (@vroland:matrix.vroland.de)APP 2 hours ago
    Hm, to me, that does not seem related to the change you did, it may just trigger the bug. Could you try to replace the calls to xmalloc_32 with xmalloc? (Or change xmalloc_32 to allocate external RAM) This could be unaligned memory access.
    ___
    Core 0 register dump:
    PC : 0x400874da PS : 0x00060d30 A0 : 0x800d641b A1 : 0x3ffdb050
    0x400874da: memmove at /builds/idf/crosstool-NG/.build/xtensa-esp32-elf/src/newlib/newlib/libc/string/memmove.c:75
    A2 : 0x40099e78 A3 : 0x40099e88 A4 :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
2021-08-25 first schematic based on tps65185
    [epaper-breakout.sch]
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2021-08-25 add additional ground area
    [epaper-breakout.kicad_pcb]
2021-08-25 add tps2113 for power switchover
    [epaper-breakout.kicad_pcb, epaper-breakout.sch]
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2021-08-25 fix testpoint labels
    [epaper-breakout-B_Cu.gbl, epaper-breakout-B_Fab.gbr, epaper-breakout-B_Mask.gbs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]
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2021-08-28 Fixed connector name
    Wrong connetor was listed - male instead of female, I found out just by ordering a wrong part...
    AXT434124 - male, on the display flex cable
    AXT334124 - female, on the board
2021-08-29 v6: fix battery switchover
    [BOM.csv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]
2021-09-06 Add postion file for manufacture JLC
    [epaper-breakout-top-jlcpcb.csv]
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2021-09-14 fix i2c for some builds
2021-09-21 Prevent conflict with buttons on LilyGOT54.7 boards
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2021-11-28 fix BOM issues
    [BOM.csv, epaper-breakout.sch]
2021-11-28 fix #108
    [epaper-breakout.kicad_pcb]
2022-01-05 Updated board.local.txt to resolve Arduino IDE compile and upload errors; see issue #133
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2022-02-13 change driver license to LGPL3 (fix #138)
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2022-02-18 Lilygo config register should be set to low on poweroff() https://github.com/vroland/epdiy/issues/92
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2022-05-07 fix build of arduino projects in CI
    Create a separate task, which installs the arduino-esp32 component first.
    Also set to use the custom partition table in sdkconfig defaults of the weather example. Otherwise the example would not successfully build by default.
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2022-05-10 Add epd_powerdown for lilygo (#179)
    * added epd_powerdown
    On lilygo disable display power but not touch screen.
    The epd power flag was re-purposed as power enable
    however it also disables the touch.
    this workaround may still leave power on to epd
    and as such may cause other problems such as grey screen.
    please also use poweroff when you sleep the system
    wake on touch will still work just not the I2C interface.
    * lilygo epd_powerdown note in readme
    Sorry it's not the prettiest thing.
    * Documentation change
    Deoxygenised the comments on the function so it will be explained in the readthedocs.io
    * Clarify readme
    * Finish readme for lily go
    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
2022-06-02 Add U3 and U7 to epaper-breakout-top-pos.csv REF https://github.com/vroland/epdiy/issues/153
    [epaper-breakout-top-pos.csv]
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2022-07-23 Modify documentation for epd_powerdown_lilygo_t5_47
    added function definition to epd_driver.h to allow Arduino to find it and fixed up the documentation
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2023-08-31 order file fixes
    [epaper-breakout.kicad_pcb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]
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2023-08-31 v7 hardware fixes
    [epaper-breakout-B_Cu.gbl, epaper-breakout-B_Mask.gbs, epaper-breakout-B_Paste.gbp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]
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2023-08-31 fix output with idf 4.x
    [lcd_driver.c]
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2023-09-04 fix calibration helper
2023-09-04 fix platformio lilygo example
    [main.cpp]
2023-09-04 fix mpd_status example
    [partitions.csv]
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2023-09-04 fix grayscale example compile
    [main.c]
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2023-09-14 terminal: remove broken include
    [main.c]
2023-09-15 commit mpd example partition file
    [partitions.csv]
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2023-10-09 fix rendering issues with I2S for some displays
    Fixes a timing issue with the RMT signal, see
    https://github.com/vroland/epdiy/issues/253.
    see #253.
    [i2s_data_bus.c]
2023-10-23 fix weather example
    [partitions.csv]
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2023-11-10 screen-diag example by @jdoubleu (#262)
    This example app implements a simple interactive shell that lets you tinker with the display. You can draw simple shapes (i.e. everything the epd driver provides), read system information, etc. I've ported some of my screen test algorithms (i.e. render_stairs and render_grid) as well.
    This can be helpful when debugging incompatible or broken displays or just experimenting with the draw functions.
    Also note: the power_on command basically obsoletes the calibration_helper example.
    [partitions_example.csv]
2023-11-11 remove hardware and mpd_status, terminal examples
    Removed because these paths are now maintained in separate repositories:
    * hardware: https://github.com/vroland/epdiy-hardware
    * mpd_status: https://github.com/vroland/epdiy-mpd
    * terminal: https://github.com/vroland/epdiy-terminal
    This improves maintainability of the core software and hardware.
    [BOM.csv, BOM_lcsc.csv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]
2023-11-16 fix CKV drift and frame restart in LCD driver (#263)
    fixes an issue where the CKV clock would drift for 8 bit screen due to the use of dummy cycles which work around an issue in the ESP32 LCD FIFO. Additionally, dummy cycles are now also used for 16-bit parallel displays, fixing a pixel offset issue. #256
    [lcd_driver.c]
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2024-05-04 fix render task priority value (#307)
    The current value was outside of the legal limits by one. Since 5.2 this was enforced causing us to hit an assert.
2024-05-10 Fix memory leak when deinitializing display feeder tasks (#306)
    [test_initialization.c]
2024-08-30 lcd_driver: fix LCD peripheral timing issue caused by ESP-IDF v5.3 API changes (#349)
    This is the fix of: https://github.com/vroland/epdiy/issues/345
    <img width="658" alt="image"
    src="https://github.com/user-attachments/assets/9d604f14-1927-4c7a-818b-87662f61e4da">
    Log see below:
    ```
    ESP-ROM:esp32s3-20210327
    Build:Mar 27 2021
    rst:0x1 (POWERON),boot:0x9 (SPI_FAST_FLASH_BOOT)
    SPIWP:0xee
    mode:DIO, clock div:1
    load:0x3fce2820,len:0x156c
    load:0x403c8700,len:0x4
    load:0x403c8704,len:0xe3c
    load:0x403cb700,len:0x2f9c
    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
    [lcd_driver.c]
2024-09-24 Refactor and test LUT functions
    Refactors waveform lookup calculations to be more maintainable and adds
    tests to avoid regressions. In the process, line masking is simplified
    and ordering problems in 2ppB mode are fixed (this should fix #284).
    8ppB now supports both PREVIOUSLY_BLACK and PREVIOUSLY_WHITE.
    [i2s_data_bus.c, main.c]
2024-11-03 Implement area clearing on the ESP32-S3
    Makes `epd_push_pixels` respect the given area on ESP32-S3 chips. This should fix #320 .
    [main.c]
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2024-12-29 Minor Bugfixing and support of non 5-bpp waveforms in waveform_hdrgen.py (#378)
    This pull request addresses two issues:
    1. Issue [326](https://github.com/vroland/epdiy/issues/326) describes:
    - Last pixel in line not updated
    - Framebuffer shifted by one row on display (first row on display not
    updated)
    2. Issue [377](https://github.com/vroland/epdiy/issues/377) describes
    minor bugs and improvements in waveform_hdrgen.py:
    - Default mode_filter is wrong
    - Temperature interval is too long if temperature range is limited
    - Approach to support non 5-bpp waveforms
    [lcd_driver.c]
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2025-03-08 Fix build on ESP-IDF 5.4, drop 4.x support (#401)
    Adds the necessary fixes to work with IDF 5.4. Additionally, we drop support for ESP-IDF < 5.0, as 5.X is now adopted almost everywhere.
    [i2s_data_bus.c, lcd_driver.c]
2025-04-12 Fix builds for versions with new lcd_hal_cal_pclk_freq
    [lcd_driver.c]
2025-04-28 Fix builds for versions with new lcd_hal_cal_pclk_freq (#413)
    There was a change in the parameters of this function in this [idf
    commit](https://github.com/espressif/esp-idf/commit/d39388fe4f4c5bfb0b52df9177307b1688f41016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).
    There are different builds with the same IDF minor version, some with,
    some without the commit. So we try to select the correct one by checking
    if the flag value is defined.
    [lcd_driver.c]
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2025-07-20 IDF 5.5 compatibility: Replace gpio_hal_iomux_func_sel (#426)
    This PR allows you to compile EPDiy with ESP-IDF 5.5.
    `gpio_hal_iomux_func_sel()` was removed in ESP IDF 5.5.
    https://github.com/espressif/esp-idf/commit/222b1ddbabfb921027a22787b8f19c1d1520011d
    [lcd_driver.c]
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2025-12-20 #451 Fix DISPLAY_TYPE_HORIZONTAL_MIRRORED issue
    [epd_board_v7_103.c]
2025-12-21 Corrections to pass clang-format
    [epd_board_v7_103.c, main.c]
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2026-01-31 fix: Restore IDF 4.x compatibility in lcd_driver.c (#461)
    ## Problem
    The current `lcd_driver.c` uses IDF 5.x APIs (`driver/rmt_tx.h`, etc.)
    which are not available in IDF 4.x. This breaks compatibility with
    Arduino ESP32 framework which still uses IDF 4.x.
    ## Solution
    Add `ESP_IDF_VERSION` conditionals to support both IDF 4.x and IDF 5.x,
    similar to other parts of the codebase.
    ## Changes
    - Add version conditionals for IDF 5.x vs 4.x includes
    (`driver/rmt_tx.h` vs `driver/rmt.h`)
    - Add IDF version conditional for `rmt_ll_set_group_clock_src()`
    signature difference
    - Wrap `RMTMEM` extern declaration for IDF 5.x only
    - Add fallback defines for `PERIPH_LCD_CAM_MODULE` and
    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
    [lcd_driver.c]
2026-03-03 fix: remove duplicate check_cache_configuration() call in epd_lcd_init
    check_cache_configuration() is already called inside
    assign_lcd_parameters_from_config(). The second call in epd_lcd_init()
    causes the pixel clock to be halved twice (e.g., 20 -> 10 -> 5 MHz)
    instead of only once on Arduino platforms where
    CONFIG_ESP32S3_DATA_CACHE_LINE_SIZE is set to 32.
    [lcd_driver.c]
2026-06-07 ci: update checkout action version, simplify checkout, prevent duplicate runs (#479)
    What started simply as a bump to the checkout action version has evolved
    into
    - bump actions/checkout to v6 - [per GitHub node.js 24
    migration](https://github.blog/changelog/2025-09-19-deprecation-of-node-20-on-github-actions-runners/)
    - arduino-esp32 checkout step didn't need to install git, just use the
    checkout action again - it is faster and does the same job!
    - trigger scope updated so updates to PRs don't result in double run of
    CI workflow
    - pin espressif/esp-idf-ci-action to v1 - [per the recommendation in the
    action docs](https://github.com/espressif/esp-idf-ci-action/tree/v1)
    - install clang-format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
2026-06-13 IDF-6.0 support ported from #463 (#477)
    This PR adds the remaining ESP-IDF 6.0 support work from #463 on top of
    current main, after the ADC and RMT migrations from that original PR
    were split out and addressed separately. It updates CI to build against
    the stable v6.0 image, adds the remaining IDF 6 build requirements and
    SDK config workaround, and adapts the ESP32 I2S and ESP32-S3 LCD paths
    for IDF 6 API/header changes while reusing the existing rmt_compat
    abstraction rather than carrying over the older duplicated RMT
    compatibility code.
    [i2s_data_bus.c, lcd_driver.c, pca9555.c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]
